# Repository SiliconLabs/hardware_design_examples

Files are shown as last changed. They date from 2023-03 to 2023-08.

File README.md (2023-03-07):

<table border="0">
  <tr>
    <td align="left" valign="middle">
    <h1>Hardware Design Examples</h1>
  </td>
  <td align="left" valign="middle">
    <a href="https://www.silabs.com/wireless">
      Wireless and RF Solutions
    </a>
  </td>
  </tr>
</table>

# Silicon Labs Hardware Design Examples #

This repository contains hardware design examples using Silicon Labs' devices. The main purpose of these examples is to accelerate the initial development process by providing a ready-to-use hardware platform.

Besides the design files, typically a test report and/or a user's manual is included summarizing some performance details of a built test unit sample.

## How to use the examples ##
The designs include complete manufacturing data files that can be used to fabricate the PCBs and pupolate them with the required components. After these steps the assembled units can be used to start the software/firmware development.

The designs can be also used as a starting point for further hardware development and modified freely according to the specific requirements.

## Organization of the Hardware Design Examples (Branches and Folders) ##
The examples are organized into branches of this repository based on the used device family. The designs belonging to the same device family can be found in the branch named accordingly.

Under the branches the folder naming convention is the following:

DeviceFamily_PackageType_Frequency_TXPower_NumberOfPCBLayers_OtherInformation\

## Examples ##

For a list of examples in this repository see the README content on the master branch.

## Disclaimer / Terms and Conditions ##

The Hardware Design Examples in this repository are provided AS IS. By downloading and using them, the user assumes and bears all liability emerging from the application of these examples.

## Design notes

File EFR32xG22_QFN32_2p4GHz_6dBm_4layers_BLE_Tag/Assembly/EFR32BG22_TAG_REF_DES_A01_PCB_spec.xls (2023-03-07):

PCB Specification of EFR32BG22_TAG_REF_DES_A01 Silicon Labs |  |  | 2020-07-06
Revision history
1
REVISION |  | 1
MECHANICAL SPECIFICATION
PCB Name |  | BG22_Tag
PCB size
Tolerances for all the dimensions |  | IPC600A(G) class 2
Core Material |  | FR-4, UL 94V-0
Substarte construction
Operating temperature range |  | -
Copper | 18um
 | prepreg 1080 63um
Copper | 18um
FR4 | Core FR4 510um 18/18
Copper | 18um
 | prepreg 1080 63um
Copper | 18um
Surface Finnishing
 | Conductor Plating | Copper
 | Pad/Land Pattern Coating | Immersion Gold
 | Solder Resist | Blue
Controlled impedance |  | NO
Silckscreen |  | YES/Top
Number of Layers |  | 4
Total Number of Drilled Holes
DESIGN RULES
Minimum Conductor Width |  | 100 um
Minimum Clearance |  | 150 um
Minimum PTH Drill Size |  | 200 um
Minimum Annular Ring |  | 100 um
TEST SPECIFICATION
Electrical Testing |  | Double side 100 % electrical testing
ADDITIONAL INFORMATION
Related CAM files |  | EFR32BG22_TAG_REF_DES_A01_Gerbers.zip
Specificatio Approved:
Customer:
Name:
Date:

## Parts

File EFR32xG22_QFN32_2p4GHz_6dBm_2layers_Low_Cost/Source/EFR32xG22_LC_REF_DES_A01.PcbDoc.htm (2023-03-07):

Date | : | 2022. 03. 07.
Time | : | 15:21:19
Filename | : | C:\Users\dasimon\Dropbox (Silicon Labs)\IoT Apps Wireless HW\Virtual Reference Designs\EFR32xG22_LC_REF_DES\release\latest\EFR32xG22_LC_REF_DES_A02\Source\EFR32xG22_LC_REF_DES_A01.PcbDoc
Version | Warning
Release 17.0 | CAUTION - Component parameters added.
Release 17.0 | CAUTION - Support of backdrilling
Release 17.1 | CAUTION - Support of waived violations
Release 17.1 | CAUTION - Support of object specific keepouts

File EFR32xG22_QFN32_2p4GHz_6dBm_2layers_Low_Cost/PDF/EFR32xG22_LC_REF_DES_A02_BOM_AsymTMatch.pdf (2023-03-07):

EFR32xG22 Low Cost Reference Design EFR32xG22_LC_REF_DES, Revision A02

Bill of Materials

ITEM | QTY | REFDES | DESCRIPTION | MANUFACTURER | PART NUMBER
1 | 1 | C2 | CAPACITOR, CERAMIC, 1.3PF, ±0.1PF, 50V, 0201 (0603 METRIC) | MURATA | GRM0335C1H1R3BA01D
2 | 1 | Z1 | INDUCTOR, THICK FILM, 3.0NH, ±0.1NH, 500MA 200mOhm Max 0201 (0603 METRIC) | MURATA | LQP03TN3N0B02D
3 | 1 | Z2 | CAPACITOR, CERAMIC, 18PF, ±1%, 25V, 0201 (0603 METRIC) | MURATA | GJM0335C1E180GB01D
4 | 5 | C4, C6, C9, C13, C15 | CAPACITOR, CERAMIC, 0.1UF, ±10%, 25V, 0201 (0603 METRIC) | MURATA | GRM033C81E104KE14D (https://www.digikey.com/product-detail/en/murata-electronics/GRM033C81E104KE14D/490-10403-1-ND/5026280)
5 | 2 | C5, C7 | CAPACITOR, CERAMIC,120PF, 50V, ±5% 0201 (0603 METRIC) | MURATA | GRM0335C1H121FA01D
6 | 1 | C8 | CAPACITOR, CERAMIC, 10UF, ±10%, 25V, 0603 (1608 METRIC) | MURATA | GRM188R61E106KA73D (https://www.digikey.com/product-detail/en/murata-electronics/GRM188R61E106KA73D/490-18214-1-ND/9867943)
7 | 1 | C10 | CAPACITOR, CERAMIC, 1UF, ±10%, 25V, 0402 (1005 METRIC) | MURATA | GRM155R61E105KA12D
8 | 1 | C11 | CAPACITOR, CERAMIC, 10NF, ±10%, 25V, 0201 (0603 METRIC) | MURATA | GRM033R71E103KE14D
9 | 1 | C12 | CAPACITOR, CERAMIC, 1UF, ±10%, 25V, 0603 (1608 METRIC) | MURATA | GCM188R71E105KA64D
10 | 1 | C14 | CAPACITOR, CERAMIC, 4.7UF, ±10%, 6.3V, 0603 (1608 METRIC) | SAMSUNG ELECTRO-MECHANICS | CL10B475KQ8NQNC
11 | 1 | C16 | CAPACITOR, CERAMIC, 1UF, ±10%, 25V, 0201 (0603 METRIC) | SAMSUNG ELECTRO-MECHANICS | CL03A105KP3NSNC
12 | 1 | C18 | CAPACITOR, CERAMIC, 1UF, ±10%, 25V, 0805 (2012 METRIC) | SAMSUNG ELECTRO-MECHANICS | CL21B105KAFNNNE
13 | 1 | L1 | INDUCTOR, THICK FILM, 2.7NH, ±0.1NH, 500MA 200mOhm Max 0201 (0603 METRIC) | MURATA | LQP03TN2N7B02D
14 | 2 | L2, L3 | FERRITE BEAD, 1 KOMHS @ 100MHZ, 350MA, 0402 (1005 METRIC) | MURATA | BLM15AX102SZ1D (https://www.digikey.com/product-detail/en/murata-electronics/BLM15AX102SZ1D/490-16654-1-ND/7595576)
15 | 1 | L5 | INDUCTOR, MULTILAYER, 2.2UH, 750MA 300mOHMS 0603 (1608 METRIC) | TDK | CIG10W2R2MNC (https://www.digikey.com/product-detail/en/samsung-electro-mechanics/CIG10W2R2MNC/1276-6877-1-ND/7041277)
16 | 1 | P1 | CONN HEADER SMD 10POS 1.27MM | SAMTEC INC. | FTSH-105-01-F-DV-K
17 | 1 | P2 | CONNECTOR, U.FL ,RF COAXIAL, SMT | TE CONNECTIVITY | 1909763-1
18 | 1 | PCB1 | PRINTED CIRCUIT BOARD
19 | 6 | R1, R2, R4, R8, R10,R13 | RESISTOR, THICK FILM, 0 OHM, JUMPER, 0.05W, 1/20W, 0201 (0603 METRIC) | PANASONIC | ERJ-1GN0R00C (https://www.digikey.com/product-detail/en/panasonic-electronic-components/ERJ-1GN0R00C/P15979CT-ND/3982319)
20 | 1 | U1 | IC, COMMUNICATIONS, EFR32MG22, -40C TO 125C, SOC, ARM CORTEX-M33, 32K RAM, 512K FLASH, 32-QFN | SILICON LABS | EFR32MG22A224F512GN32 - C
21 | 1 | X1 | OSCILLATOR, CRYSTAL, 38.4MHZ, ±10PPM, 10PF | TAI-SAW | TZ2205E
22 | 1 | X2 | OSCILLATOR, CRYSTAL, 32.768KHZ, ±20PPM, 7PF, 2-SMD | EPSON | FC-135 32.7680KA-AG5
23 | 1 | BAT1 | BATTERY HOLDER COIN 20MM SMD | MPD (MEMORY PROTECTION DEVICES) | BU2032SM-JJ-GTR
24 | 1 | L4 | INDUCTOR, THICK FILM, 5.1NH, ±3%, 350MA 400mOhm Max 0201 (0603 METRIC) | MURATA | LQP03TN5N1H02
25 | 1 | C19 | CAPACITOR, CERAMIC, 0.7PF, ±0.05PF, 50V, 0201 (0603 METRIC) | MURATA | GRM0335C1HR70WA01
Total | 36

EFR32xG22 Low Cost Reference Design EFR32xG22_LC_REF_DES, Revision A02

Reduced Bill of Materials

ITEM | QTY | REFDES | DESCRIPTION | MANUFACTURER | PART NUMBER
1 | 1 | C2 | CAPACITOR, CERAMIC, 1.3PF, ±0.1PF, 50V, 0201 (0603 METRIC) | MURATA | GRM0335C1H1R3BA01D
2 | 1 | Z1 | INDUCTOR, THICK FILM, 3.0NH, ±0.1NH, 500MA 200mOhm Max 0201 (0603 METRIC) | MURATA | LQP03TN3N0B02D
3 | 1 | Z2 | CAPACITOR, CERAMIC, 18PF, ±1%, 25V, 0201 (0603 METRIC) | | GJM0335C1E180GB01D
4 | 1 | C4 | CAPACITOR, CERAMIC, 0.1UF, ±10%, 25V, 0201 (0603 METRIC) | MURATA | GRM033C81E104KE14D (https://www.digikey.com/product-detail/en/murata-electronics/GRM033C81E104KE14D/490-10403-1-ND/5026280)
5 | 2 | C5,C7* | CAPACITOR, CERAMIC,120PF, 50V, ±5% 0201 (0603 METRIC) | MURATA | GRM0335C1H121FA01D
6 | 1 | C8 | CAPACITOR, CERAMIC, 10UF, ±10%, 25V, 0603 (1608 METRIC) | MURATA | GRM188R61E106KA73D (https://www.digikey.com/product-detail/en/murata-electronics/GRM188R61E106KA73D/490-18214-1-ND/9867943)
7 | 1 | C10 | CAPACITOR, CERAMIC, 1UF, ±10%, 25V, 0402 (1005 METRIC) | MURATA | GRM155R61E105KA12D
8 | 1 | C14 | CAPACITOR, CERAMIC, 4.7UF, ±10%, 6.3V, 0603 (1608 METRIC) | SAMSUNG ELECTRO-MECHANICS | CL10B475KQ8NQNC
9 | 1 | C16 | CAPACITOR, CERAMIC, 1UF, ±10%, 25V, 0201 (0603 METRIC) | SAMSUNG ELECTRO-MECHANICS | CL03A105KP3NSNC
10 | 1 | C18 | CAPACITOR, CERAMIC, 1UF, ±10%, 25V, 0805 (2012 METRIC) | SAMSUNG ELECTRO-MECHANICS | CL21B105KAFNNNE
11 | 1 | L1 | INDUCTOR, THICK FILM, 2.7NH, ±0.1NH, 500MA 200mOhm Max 0201 (0603 METRIC) | MURATA | LQP03TN2N7B02D
12 | 1 | L2 | FERRITE BEAD, 1 KOMHS @ 100MHZ, 350MA, 0402 (1005 METRIC) | MURATA | BLM15AX102SZ1D (https://www.digikey.com/product-detail/en/murata-electronics/BLM15AX102SZ1D/490-16654-1-ND/7595576)
13 | 1 | L5 | INDUCTOR, MULTILAYER, 2.2UH, 750MA 300mOHMS 0603 (1608 METRIC) | TDK | CIG10W2R2MNC (https://www.digikey.com/product-detail/en/samsung-electro-mechanics/CIG10W2R2MNC/1276-6877-1-ND/7041277)
14 | 1 | P1 | CONN HEADER SMD 10POS 1.27MM | SAMTEC INC. | FTSH-105-01-F-DV-K
15 | 1 | P2 | CONNECTOR, U.FL ,RF COAXIAL, SMT | TE CONNECTIVITY | 1909763-1
16 | 1 | PCB1 | PRINTED CIRCUIT BOARD
17 | 6 | R1, R2, R4, R8, R10,R13 | RESISTOR, THICK FILM, 0 OHM, JUMPER, 0.05W, 1/20W, 0201 (0603 METRIC) | PANASONIC | ERJ-1GN0R00C (https://www.digikey.com/product-detail/en/panasonic-electronic-components/ERJ-1GN0R00C/P15979CT-ND/3982319)
18 | 1 | U1 | IC, COMMUNICATIONS, EFR32MG22, -40C TO 125C, SOC, ARM CORTEX-M33, 32K RAM, 512K FLASH, 32-QFN | SILICON LABS | EFR32MG22A224F512GN32 - C
19 | 1 | X1 | OSCILLATOR, CRYSTAL, 38.4MHZ, ±10PPM, 10PF | TAI-SAW | TZ2205E
20 | 1 | X2 | OSCILLATOR, CRYSTAL, 32.768KHZ, ±20PPM, 7PF, 2-SMD | EPSON | FC-135 32.7680KA-AG5
21 | 1 | BAT1 | BATTERY HOLDER COIN 20MM SMD | MPD (MEMORY PROTECTION DEVICES) | BU2032SM-JJ-GTR
22 | 1 | L3 | RESISTOR, THICK FILM, 0 OHM, JUMPER, 0402 (1005 METRIC)
23 | 1 | L4 | INDUCTOR, THICK FILM, 5.1NH, ±3%, 350MA 400mOhm Max 0201 (0603 METRIC) | MURATA | LQP03TN5N1H02
24 | 1 | C19 | CAPACITOR, CERAMIC, 0.7PF, ±0.05PF, 50V, 0201 (0603 METRIC) | MURATA | GRM0335C1HR70WA01
Total | 30

Notes:
*C7 is not needed for devices with maximum output power of 0 dBm

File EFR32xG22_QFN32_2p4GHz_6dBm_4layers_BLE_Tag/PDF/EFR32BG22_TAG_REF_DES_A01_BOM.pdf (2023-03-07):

Bill Of Materials for EFR32BG22_TAG_REF_DES_A00.sch on Thu Jul 23 10:30:01 2020
Column1 | Column2 | Column3 | Column4 | Column5 | Column6 | Column7 | Column8 | Column9 | Column10
Item | Quantity | Reference | Value | Manufacturer | Part Number | Description | Tolerance | Package | Distributor
1 | 1 | U3 | | Bosch Sensortec | BMA400 | Accelerometer 2-16G 12LGA | | 12-LGA (2x2mm) | Digikey
2 | 5 | C6, C11, C13, C16, C21 0.1uF | any | General Ceramic Chip Capacitor | +/-10% | 0201
3 | 2 | C7, C12 | 12pF | any | | Ceramic Chip Capacitor | +/-2% | 0201
4 | 1 | C17 | 18pF | Murata | GJM0335C1E180GB01D | Ceramic Chip Capacitor | +/-2% | 0201
5 | 1 | C3 | 1.2pF | Murata | GRM0335C1H1R2WA01D | Ceramic Chip Capacitor | +/-0.05pF | 0201
6 | 1 | C2 | 1.3pF | Murata | GRM0335C1H1R3BA01D | Ceramic Chip Capacitor | +/-0.1pF | 0201
7 | 1 | C19 | NP | | | Ceramic Chip Capacitor | +/-0.1pF | 0201
8 | 5 | C9-10, C14-15 | 1uF | any | | Ceramic Chip Capacitor | +/-20% | 0201
| | C18
9 | 1 | C1 | 1.7pF | Murata | GRM0335C1H1R7BA01D | Ceramic Chip Capacitor | +/-0.1pF | 0201
10 | 1 | C4 | 2.2uF | any | | Ceramic Chip Capacitor | 10% | 0402
11 | 2 | C5 C8 | 4.7uF | any | | Ceramic Chip Capacitor | +/-20% | 0402
12 | 1 | Y3 | | MPD (Memory Protection
| | | | Devices) | BC-2003-TR | Battery Retainer Coin, 20.0mm 1 Cell
| | | | | | SMD (SMT) Tab, Coin cell CR2032
| | | | | | battery holder | | | Digikey
13 | 1 | U5 | | Infineon Technologies | DPS310XTSA1 | Pressure Sensor | | 8-pin LGA
14 | 1 | U1 | | Silicon Labs | EFR32BG22C224F512GM32 | | | QFN32
15 | 7 | TP1-7
16 | 1 | J1 | HEADER, 10PIN | Samtec | FTSH-105-01-F-DV | Header, 10 pin, SMD, 1.27mm, dual
| | | | | | row | | HEADER_10PIN_1.2
| | | | | | | | 7MM_SMD_DUAL | Q-Flex
17 | 7 | HOL1-7 | N/A | N/A | | N/A | | | N/A
18 | 2 | L1, L5 | 5.6nH | Murata | LQP03TN5N6H02D | Chip Coil | +-3% | 0201
19 | 1 | L2 | 6.2nH | Murata | LQP03TN6N2H02D | Chip Coil | +-3% | 0201
20 | 1 | L6 | 2.2µH | Taiyo Yuden | MAMK2520T2R2M | Shielded SMT Power Inductor | +/-20% | 1008
21 | 1 | L4 | 2.7nH | Murata | LQP03TN2N7B02D | Chip Inductor | +-0.1nH | 0201 | Digikey
22 | 1 | D1 | | Broadcom Limited | HSMC-C190 | Low-current LED | | 0603
23 | 1 | R5 | 0R | any | 232270671001L | Chip Resistor | N/A | 0201 | Arrow
24 | 1 | R9 | 2k | any | | Chip Resistor | N/A | 0201
25 | 1 | R2 | 0R | any | | Chip Resistor | N/A | 0402
26 | 1 | SW1 | | C&K Components | PTS820J_ | Tactile Switch, Microminiature SMT
| | | | | | Top Actuated
27 | 1 | Y1 | 32.768 kHz | AVX Corp/Kyocera Corp | ST2012SB32768C0HPWBB Crystal, 32.768 kHz, CL=7pF | 20ppm | 2.0x1.2mm
28 | 1 | Y2 | 38.4MHz | Siward Crystal Technology | XTL501200-C294-002 | Crystal, 38.4000 Mhz, 9pF -40..+85C,
| | | | | | CL=10pF, C0=3pF | 10ppm/20ppm | 2.0x1.6mm 4-pad

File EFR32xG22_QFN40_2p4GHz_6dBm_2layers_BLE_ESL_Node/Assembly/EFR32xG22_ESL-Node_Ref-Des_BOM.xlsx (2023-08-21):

Quantity | Designator | Value | Manufacturer | Part Number | Description | Comment | Tolerance | Rating | Package | Technology | Not mounted
2 | BATT1, BATT2 |  | Keystone Electronics Corp. | 2450 SMT battery holder 1052 | https://hu.mouser.com/datasheet/2/215/052-743285.pdf | BATTERY_HOLDER
5 | C1, C6, C8, C19, C28 | 100nF | Murata |  | Capacitor - ceramic |  | 10% | 10V | SMD0201 | X5R
1 | C2 | 10uF | Murata |  | Capacitor - ceramic |  | 20% | 6.3V | SMD0402 | X5R
1 | C3 | 10nF | Murata |  | Capacitor - ceramic |  | 10% | 10V | SMD0201 | X5R
1 | C4 | 1uF | Murata |  | Capacitor - ceramic |  | 20% | 6.3V | SMD0402 | X5R
2 | C5, C9 | 1uF | Murata |  | Capacitor - ceramic |  | 20% | 10V | SMD0201 | X5R
1 | C7 | 4.7uF | Murata |  | Capacitor - ceramic |  | 20% | 10V | SMD0402 | X5R
2 | C10, C12 | 15pF | Murata | GRM0335C series | Capacitor - ceramic |  | 5% |  | SMD0201 | C0G
4 | C11, C13, C20, C29 | 220nF | Murata |  | Capacitor - ceramic |  | 10% | 10V | SMD0201 | X5R
4 | C14, C15, C16, C17 |  |  |  | Capacitor - ceramic | N.M. |  |  |  |  | N.M.
2 | C18, C37[1] | 1uF | Murata |  | Capacitor - ceramic |  | 10% | 10V | SMD0402 | X5R
4 | C21[1], C22[1], C24[1], C25[1] |  |  |  | Capacitor - ceramic | N.M. |  |  | SMD0805 |  | N.M.
1 | C21[2] | 100uF | Murata |  | Capacitor - ceramic | N.M. | 20% | 6V3 | SMD1206 | X5R | N.M.
2 | C22[2], C25[2] |  |  |  | Capacitor - ceramic | N.M. |  |  | SMD1206 |  | N.M.
3 | C23, C26, C27 | 100nF | Murata |  | Capacitor - ceramic |  | 10% | 16V | SMD0402 | X7R
1 | C24[2] | 100uF | Murata |  | Capacitor - ceramic |  | 20% | 6V3 | SMD1206 | X5R
1 | C30 | 7.5pF | Murata |  | Capacitor - ceramic |  | 0.25pF | 50V | SMD0201 | NP0
1 | C31 |  |  |  | Capacitor - ceramic | N.M. |  |  | SMD0201 |  | N.M.
2 | C32, C33 | 10uF | Murata |  | Capacitor - ceramic |  | 10% | 25V | SMD0603 | X5R
1 | C34 | 0.33uF | Murata |  | Capacitor - ceramic |  | 10% | 25V | SMD0603 | X5R
8 | C35[1], C36[1], C38[1], C39[1], C40[1], C41[1], C42[1], C43[1] |  |  |  | Capacitor - ceramic | N.M. |  |  | SMD0402 |  | N.M.
6 | C35[2], C38[2], C39[2], C40[2], C41[2], C43[2] | 1uF | Murata |  | Capacitor - ceramic |  | 10% | 25V | SMD0603 | X5R
1 | C36[2] | 10uF | Murata |  | Capacitor - ceramic |  | 10% | 10V | SMD0603 | X5R
1 | C37[2] |  |  |  | Capacitor - ceramic | N.M. | 10% | 25V | SMD0603 | X5R | N.M.
1 | C42[2] | 4.7uF | Murata |  | Capacitor - ceramic |  | 10% | 25V | SMD0603 | X5R
1 | CC1 | 15pF | Murata | GRM0335C series | Capacitor - ceramic |  | 5% |  | SMD0201 | C0G
3 | CM1, CM3, CM4 |  | Murata | GRM0335C series | Capacitor - ceramic | N.M. |  |  | SMD0201 | C0G | N.M.
1 | CM2 | 1.2pF | Murata | GRM0335C series | Capacitor - ceramic |  | 0.1pF |  | SMD0201 | C0G
1 | D1 |  | Broadcom | ASCB-JTC2-0A308 | https://docs.broadcom.com/doc/ASCB-JTC2-0A308-1615-Tricolor-PLCC-4-LED-DS | 1615 Tricolor PLCC-4 LED |  |  | 1.6×1.5×1.0 mm PLCC-4 package
1 | D2 |  | ON Semiconductor | SZESD7451 | Bidirectional ESD Protection Diode |  |  |  | SOD882
3 | D3[1], D4[1], D5[1] |  | NEX (Nexperia) | PMEG4010BEA | 1A very low Vf MEGA Schottky barrier rectifier. | N.M. |  |  | SOD-323 |  | N.M.
3 | D3[2], D4[2], D5[2] |  | NEX (Nexperia) | PMEG3005EL | 30 V, 0.5A low VF MEGA Schottky barrier rectifier |  |  |  | SOD-882
1 | J1 |  | Samtec | FTSH-105-01-L-DV-K | 10-pin mini-simplicity header | FTSH_105_01_L_DV_K
7 | J2, J3, J4, J5, J6, J7, J9 |  | Amphenol ICC (FCI) | 75160-101-02LF | CONN HEADER VERT 2POS 2.54MM | Jumper_2.54mm
2 | J8, J10 |  | Amphenol ICC (FCI) | 75160-101-03LF | CONN HEADER VERT 3POS 2.54MM | Jumper_2.54mm_3p
1 | J11 |  | Amphenol ICC (FCI) | 75160-101-05LF | CONN HEADER VERT 5POS 2.54MM | Jumper_2.54mm_5p
1 | J12 |  | Hirose Electric Co. Ltd. | FH34SRJ-24S-0.5SH | FPC Connector for EPD, 0.5mm pitch, 24 pins, dual contact |  |  | 50V
1 | J13 |  | Hirose Electric Co. Ltd. | FH34SRJ-6S-0.5SH-1 | FPC Connector for Touch Interface, 0.5mm pitch, 6 pins |  |  | 50V
1 | L1[1] | 2.2uH | Murata | LQM18FN2R2M00 | DCDC Output Inductor | loss: 520mR | 20% | 120mA | SMD0603 |  | N.M.
1 | L1[2] | 2.2uH | Murata | LQM21PN2R2NGCD | DCDC Output Inductor | loss: 288mR | 30% | 800mA | SMD0805
2 | L2[1], L3[1] | 22nH |  |  | Inductor | N.M. |  |  | SMD0402 |  | N.M.
2 | L2[2], L3[2] | 1000R | Murata | BLM18AG102SN1 | Ferrite Inductor | DCR=0R5 | 25% | 400mA | SMD0603
1 | L4[1] | 47uH |  |  | Inductor | N.M. |  |  | SMD0805 |  | N.M.
1 | L4[2] | 10uH | Taiyo Yuden | BRC2016T100M | Inductor | 520mR | 20% | 450mA | SMD0806
1 | L4[3] |  |  |  | Inductor | N.M. |  |  | 2.5x2.0x1.2 (2520) |  | N.M.
1 | L4[4] | 10uH | TAY |  | Inductor | 450mR | 20% | 0.5A |  |  | N.M.
2 | LM1, LM2 | 2.7nH | Murata | LQP03TN2N7B02 (LQP03TN series) | Inductor |  | 0.1nH |  | SMD0201
1 | LM3 |  | Murata | LQP03TN series | Inductor | N.M. | 3% |  | SMD0201 |  | N.M.
3 | R1, R31, R40 | 0R |  |  | Resistor | N.M. |  |  | SMD0201 |  | N.M.
5 | R2, R5, R32, R39, RM1 | 0R |  |  | Resistor |  |  |  | SMD0201
7 | R3, R16, R17, R19, R33, R35, R36 | 0R |  |  | Resistor |  |  |  | SMD0603
6 | R4, R22, R23, R30, R37, R38 | 0R |  |  | Resistor | N.M. |  |  | SMD0603 |  | N.M.
1 | R6 | 470R |  |  | Resistor |  |  |  | SMD0201
3 | R7, R9, R12 | 0R |  |  | Resistor |  |  |  | SMD0402
3 | R8, R10, R11 | 0R |  |  | Resistor | N.M. |  |  | SMD0402 |  | N.M.
3 | R13, R14, R15 | 4k7 | Yageo |  | Resistor |  | 5% |  | SMD0201
1 | R18 | 330k |  |  | Resistor |  |  |  | SMD0201
4 | R20, R27, R28, R29 | 100k | Yageo |  | Resistor |  | 5% |  | SMD0201
1 | R21 | 10k | Yageo |  | Resistor |  | 5% |  | SMD0201
2 | R24, R25 | 100R | Yageo |  | Resistor |  | 5% |  | SMD0201
1 | R26 | 270R | Yageo |  | Resistor |  | 5% |  | SMD0201
1 | R34 |  |  |  | Resistor | N.M. |  |  | SMD0201 |  | N.M.
1 | R41 | 0R47 |  |  | Resistor |  | 1% |  | SMD0402
2 | SW1, SW2 |  | CK Components | PTS810 SJM 250 SMTR LFS | User and Reset push button | PTS810
1 | T1 |  | NEX (Nexperia) | PMZ350UPE | P-Channel Trench MOSFET |  |  | 30V | SOT-883
1 | T2 |  | NEX (Nexperia) | PMCB60XNZ | N-Channel Trench MOSFET |  |  | 30V | SOT8026
3 | T3, T4, T5 |  | NEX (Nexperia) | PMZ200UNE; PMZ370UNEYL | N-Channel Trench MOSFET |  |  | 30V | SOT-883
1 | U1 |  | Silicon Labs | EFR32BG22C224F512GM40 | 40-pin Wireless (BLE) MCU | EFR32BG22C224F512GM40 |  |  | QFN40
1 | U2[1] |  | Macronix | MX25R8035FM1IL0 | ULTRA LOW POWER, 8M-BIT FLASH MEMORY | MX25R8035F |  |  | 8-SOP (150mil)
1 | U2[2] |  | Macronix | MX25R8035FM2IL0; MX25R8035FM2IH0 | ULTRA LOW POWER, 8M-BIT FLASH MEMORY | MX25R8035F |  |  | 8-SOP (200mil) |  | N.M.
1 | U3[1] |  | NXP | NT3H2111W0FT1 | NFC NTAG | NT3H2111W0FT1/NXP/SO8 |  |  | SO8 |  | N.M.
1 | U3[2] |  | NXP | NT3H2111W0FHK | NFC NTAG | NT3H2111/NXP/XQFN-8 |  |  | XQFN-8
1 | U4 |  | Bosch Sensortec | BMA400 | Accelerometer 2-16G 12-LGA | BMA400 |  |  | 12-LGA (2x2mm)
1 | U5 |  | Maxim Integrated | MAX1759 | https://datasheets.maximintegrated.com/en/ds/MAX1759.pdf | Buck/Boost Regulating Charge Pump in µMAX |  | 5.5 V | 10-pin µMAX
1 | Y1 | 38.4MHz | KDS; Abracon LLC | DSX211SH 1ZZNAE38400AB0A; ABM11W-38.4000MHZ-8-B1U-T3 | HFXO | accuracy: 10ppm; load capacitance: 8pF | 10ppm |  | 2.0x1.6x0.5mm
1 | Y2 | 32.768kHz | KDS; Micro Crystal AG | DST210A 1TJG125DP1A0012; CM8V-T1A-32.768KHZ-9PF-20PPM-TA-QC | LFXO | accuracy: 12.5ppm | 20ppm |  | 2.0x1.2x0.55mm

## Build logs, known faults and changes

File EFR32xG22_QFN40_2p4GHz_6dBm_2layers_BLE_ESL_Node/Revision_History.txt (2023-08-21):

Rev A02:
Fixing DCDC configuration mounting options
Fixing BMA400 interface mounting options
Fixing silk screen and DRC errors

Rev A01:
Adding VEXT connector to support external supply
Adding Touch Interface
Adding test header for I2C
Fixing RGB LED pin mapping
32kHz crystal pad area fix
EPD DCDC switching FET changed to PMCB60XNZ

Rev A00: 
Original release

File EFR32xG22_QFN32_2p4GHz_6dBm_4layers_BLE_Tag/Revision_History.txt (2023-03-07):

Rev A00: 
Original release

Rev A01:
- R9 resistor value change to 2kOhm
- Fixing LED orientation by rotating it by 180 degrees

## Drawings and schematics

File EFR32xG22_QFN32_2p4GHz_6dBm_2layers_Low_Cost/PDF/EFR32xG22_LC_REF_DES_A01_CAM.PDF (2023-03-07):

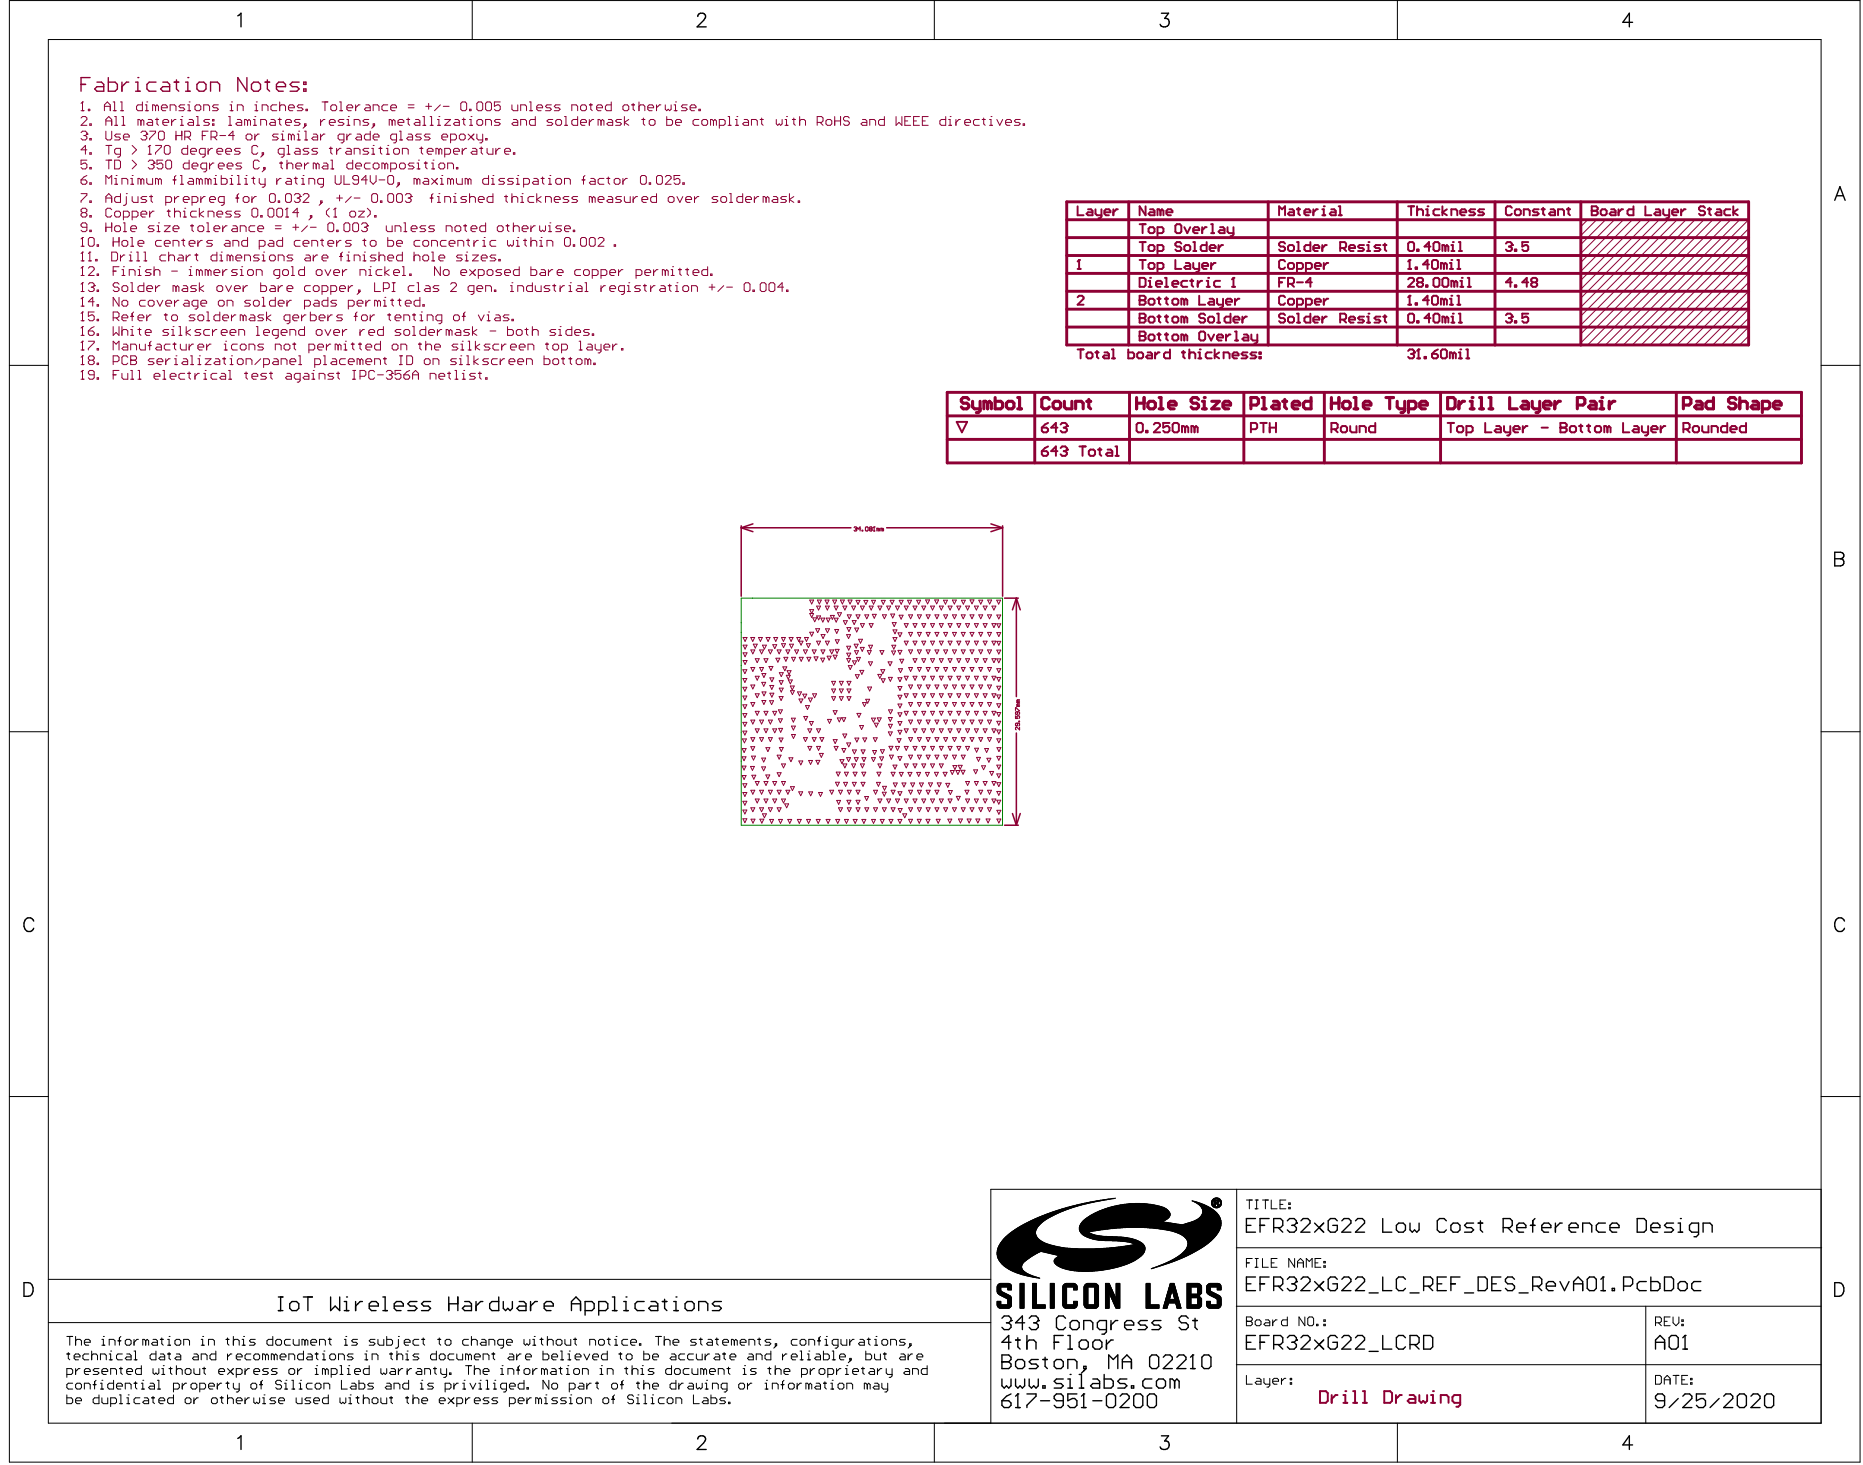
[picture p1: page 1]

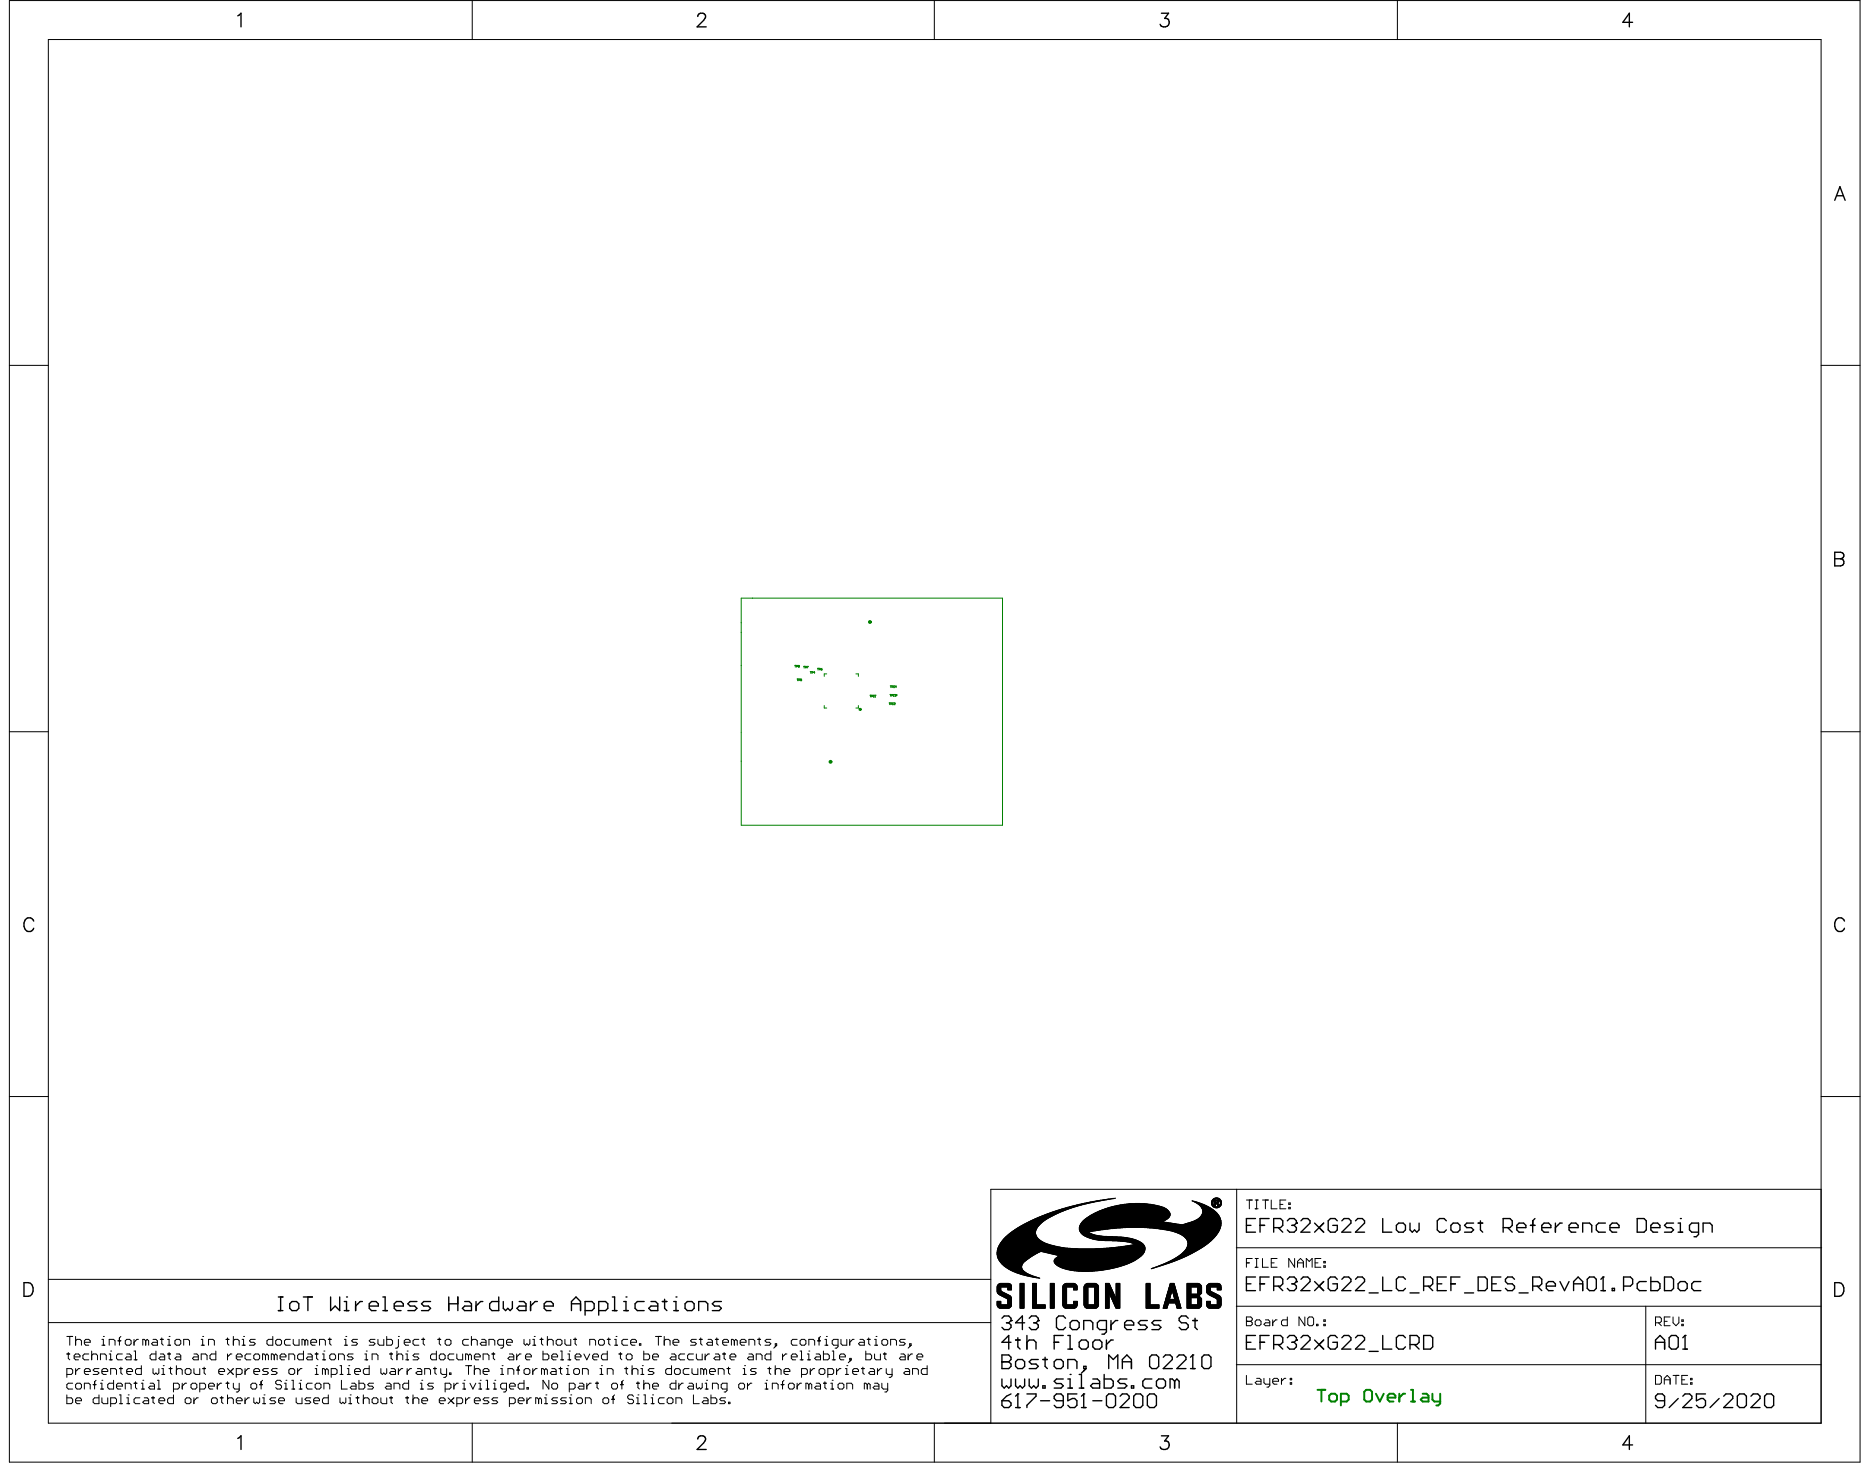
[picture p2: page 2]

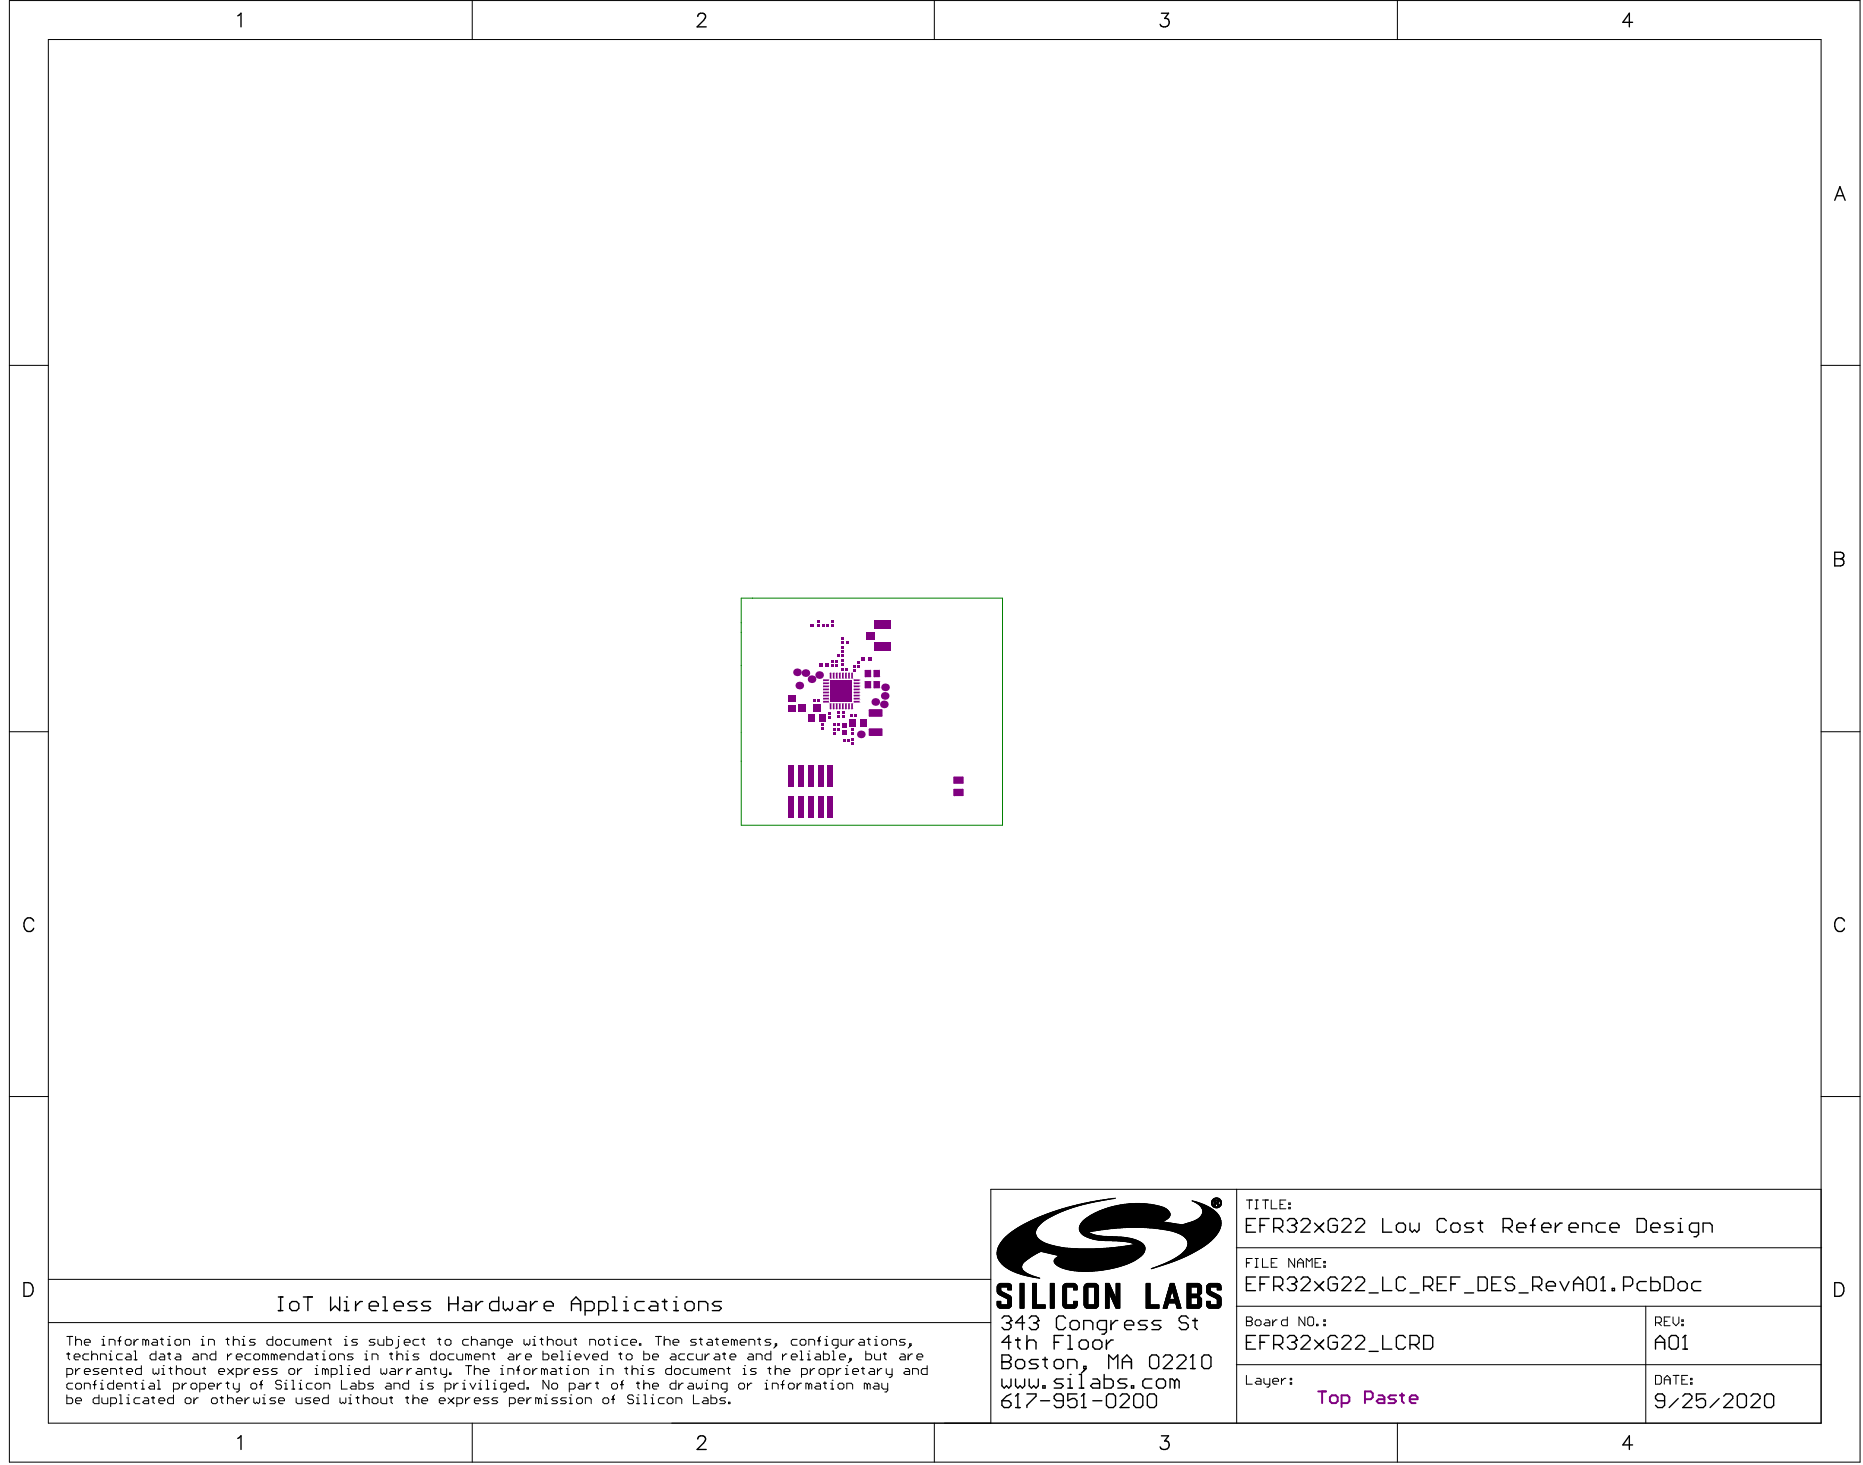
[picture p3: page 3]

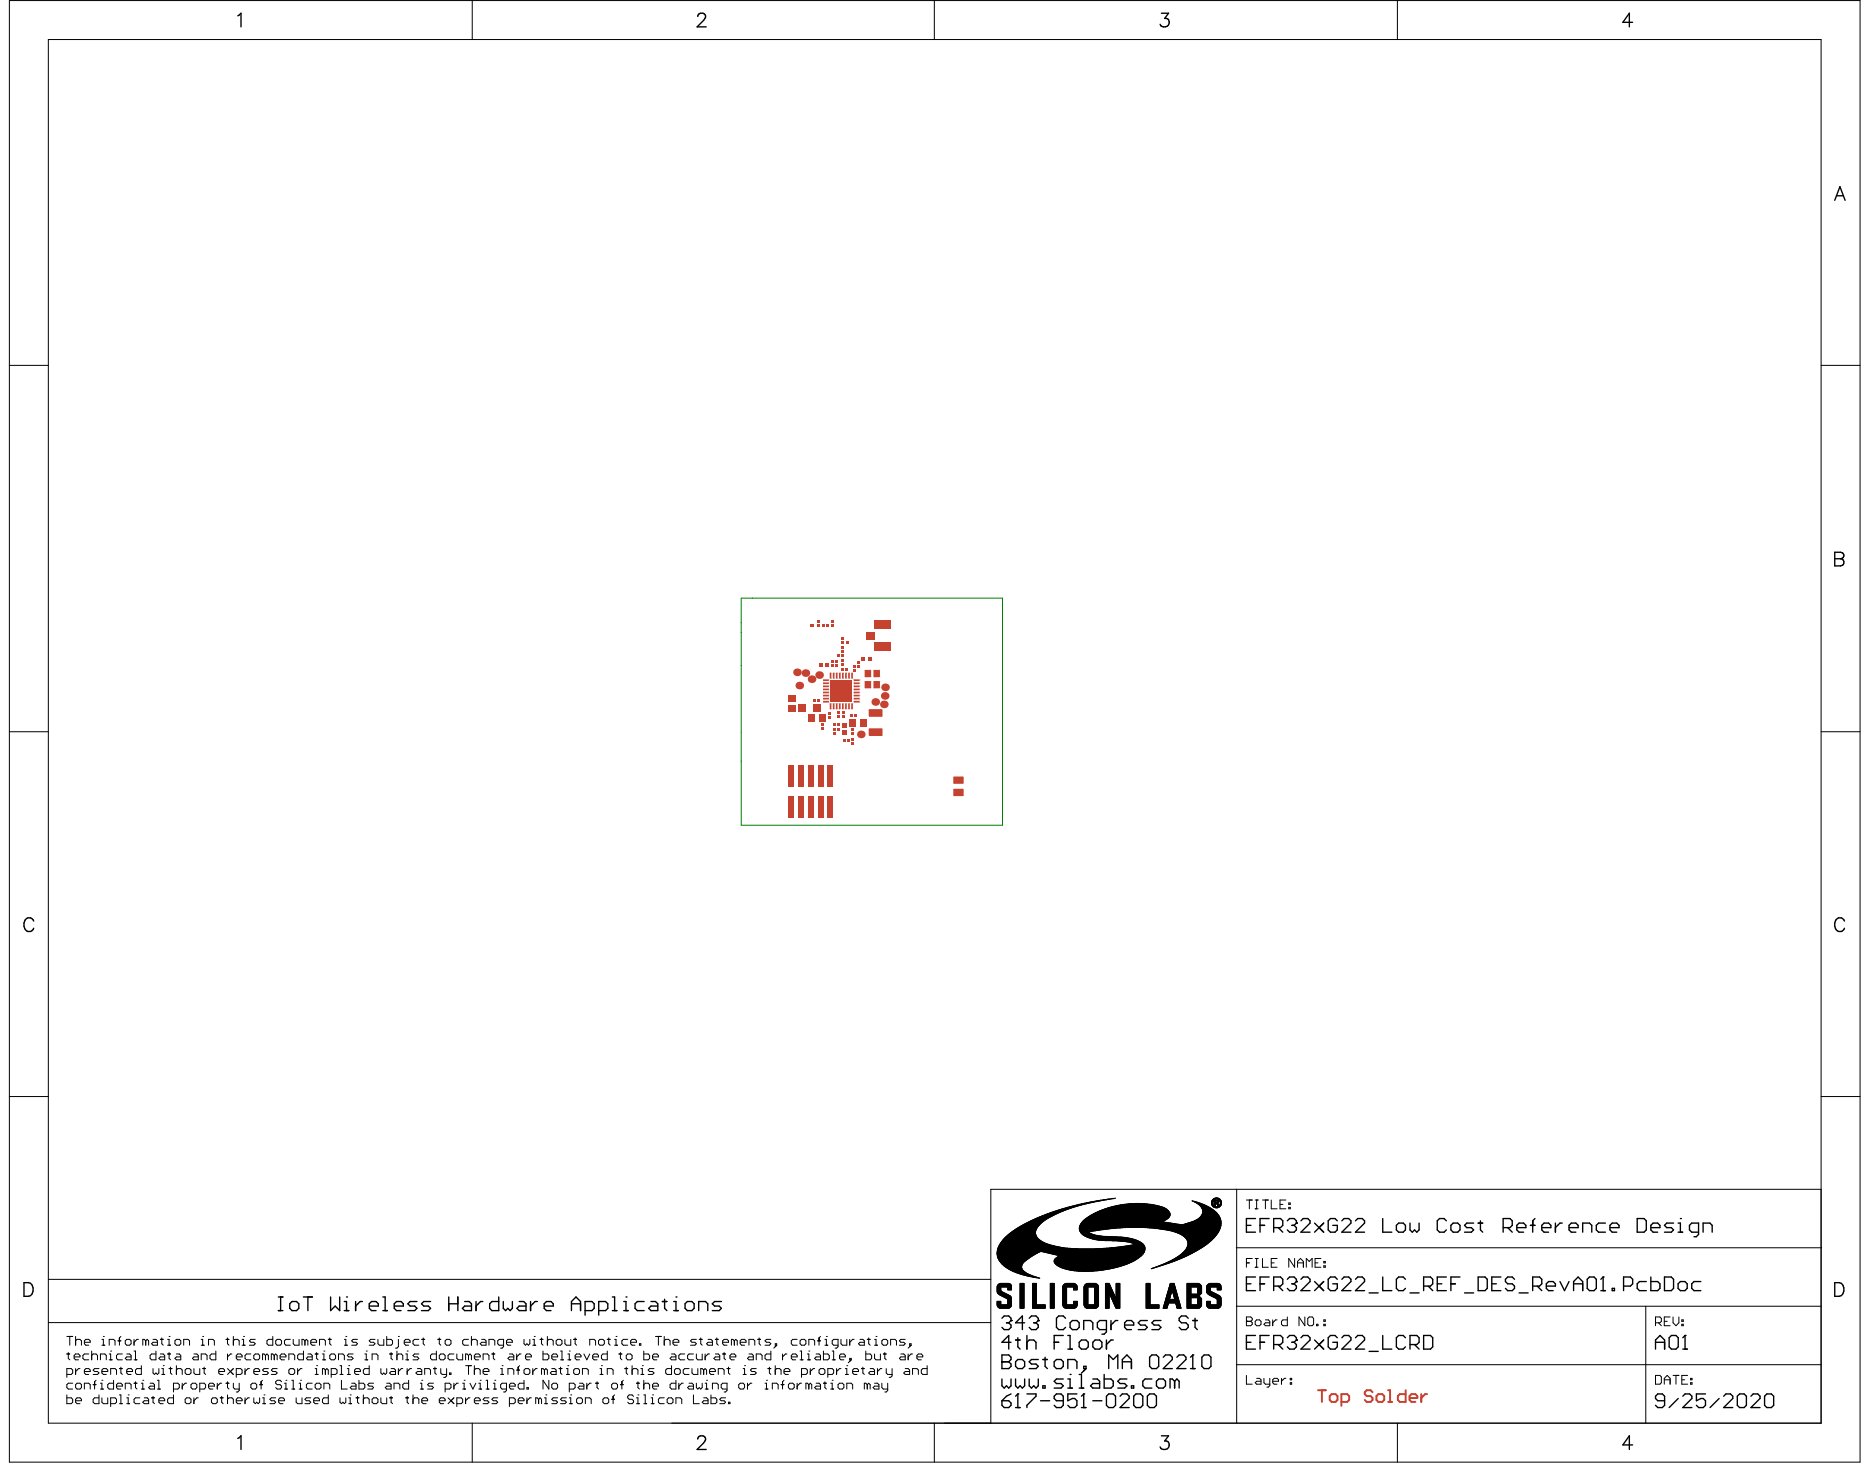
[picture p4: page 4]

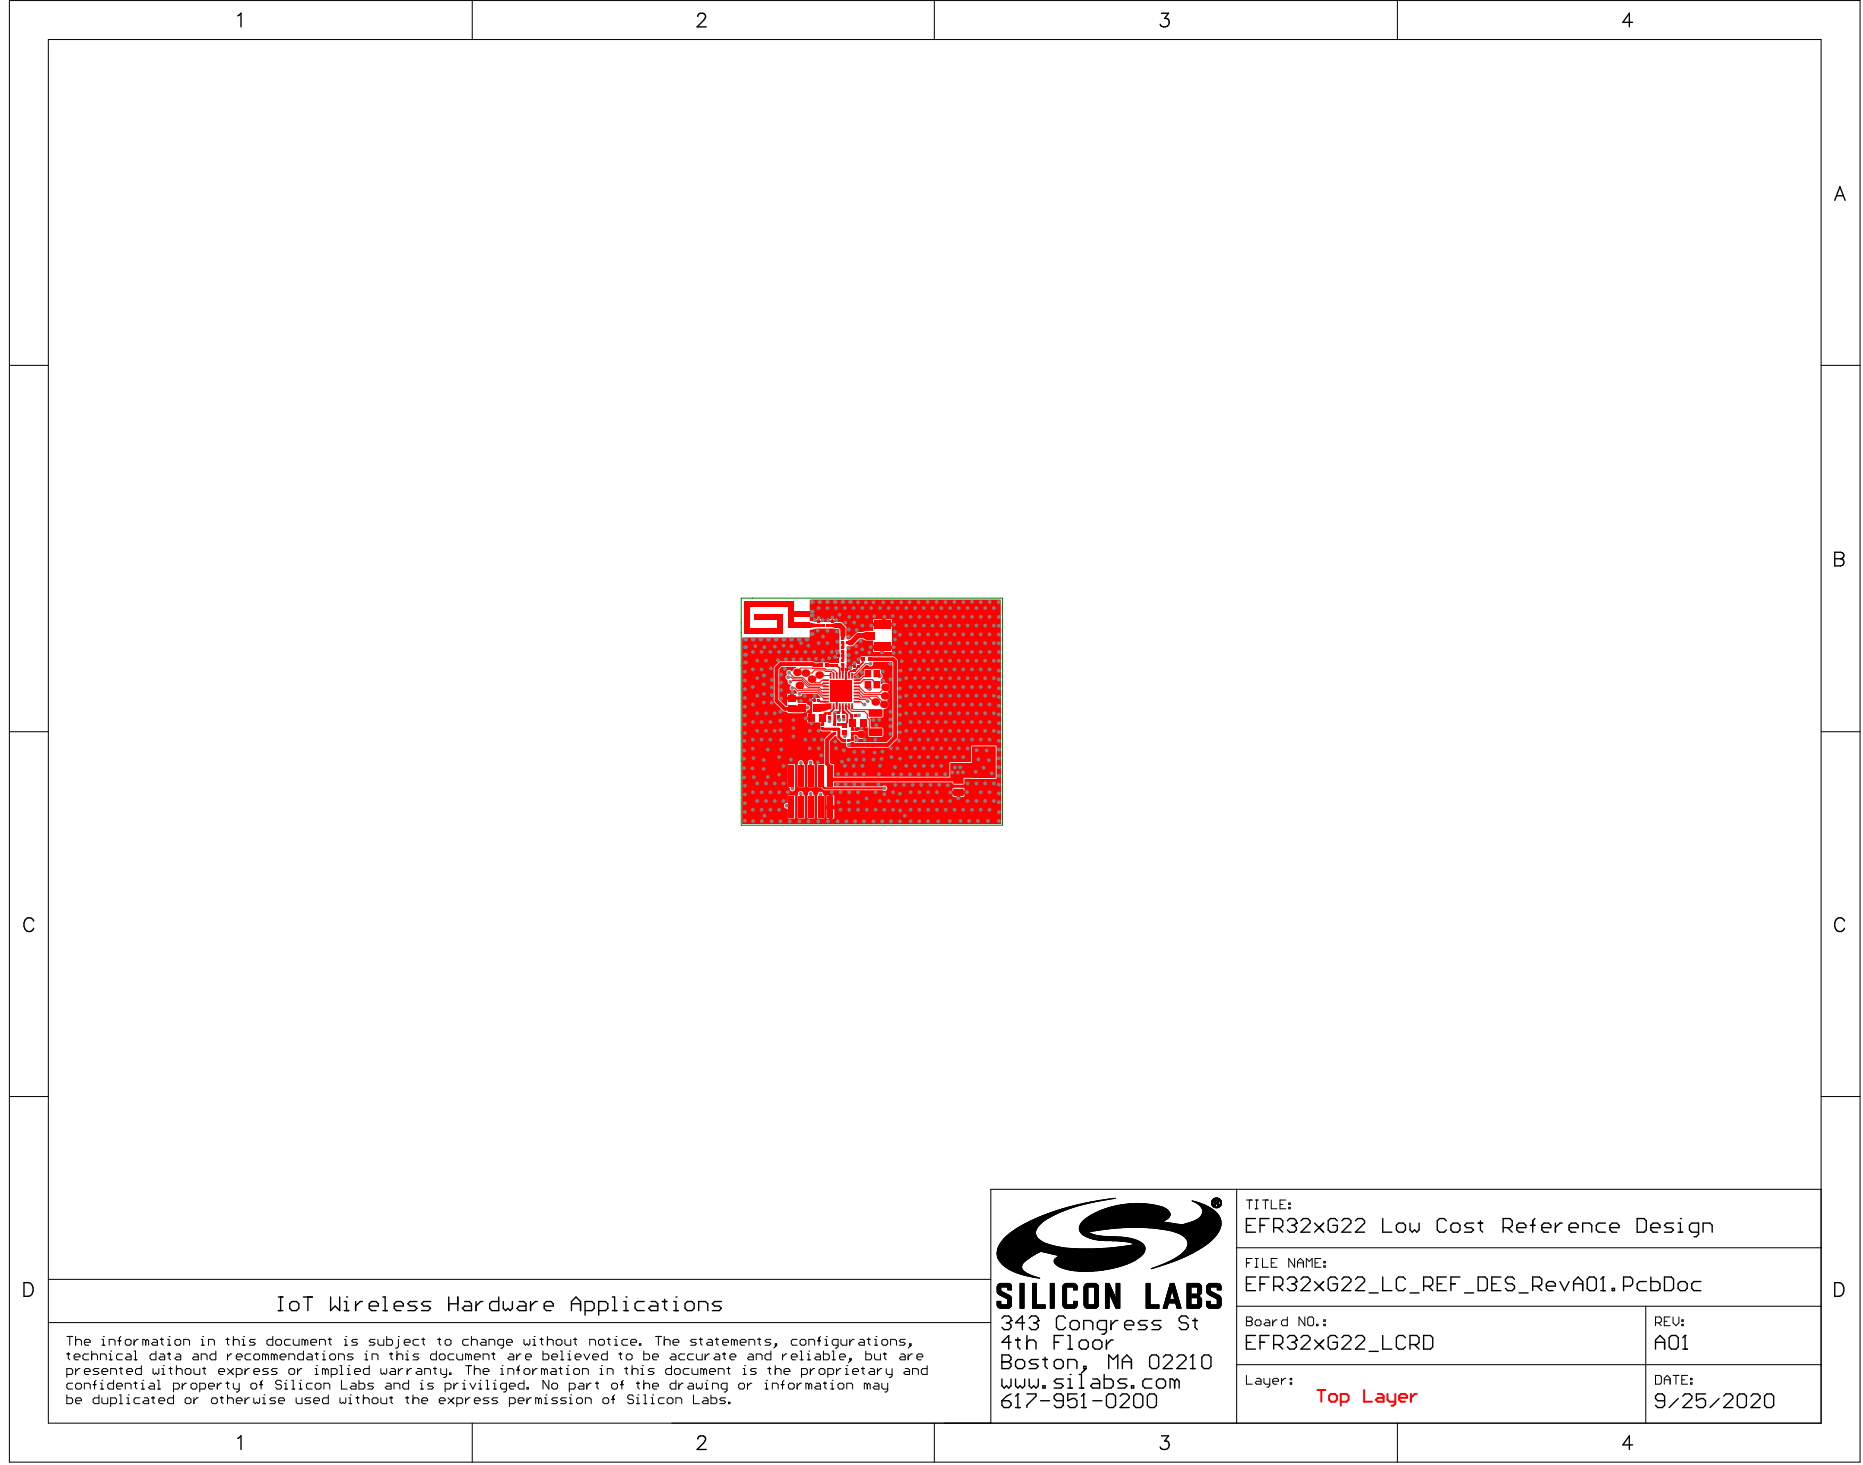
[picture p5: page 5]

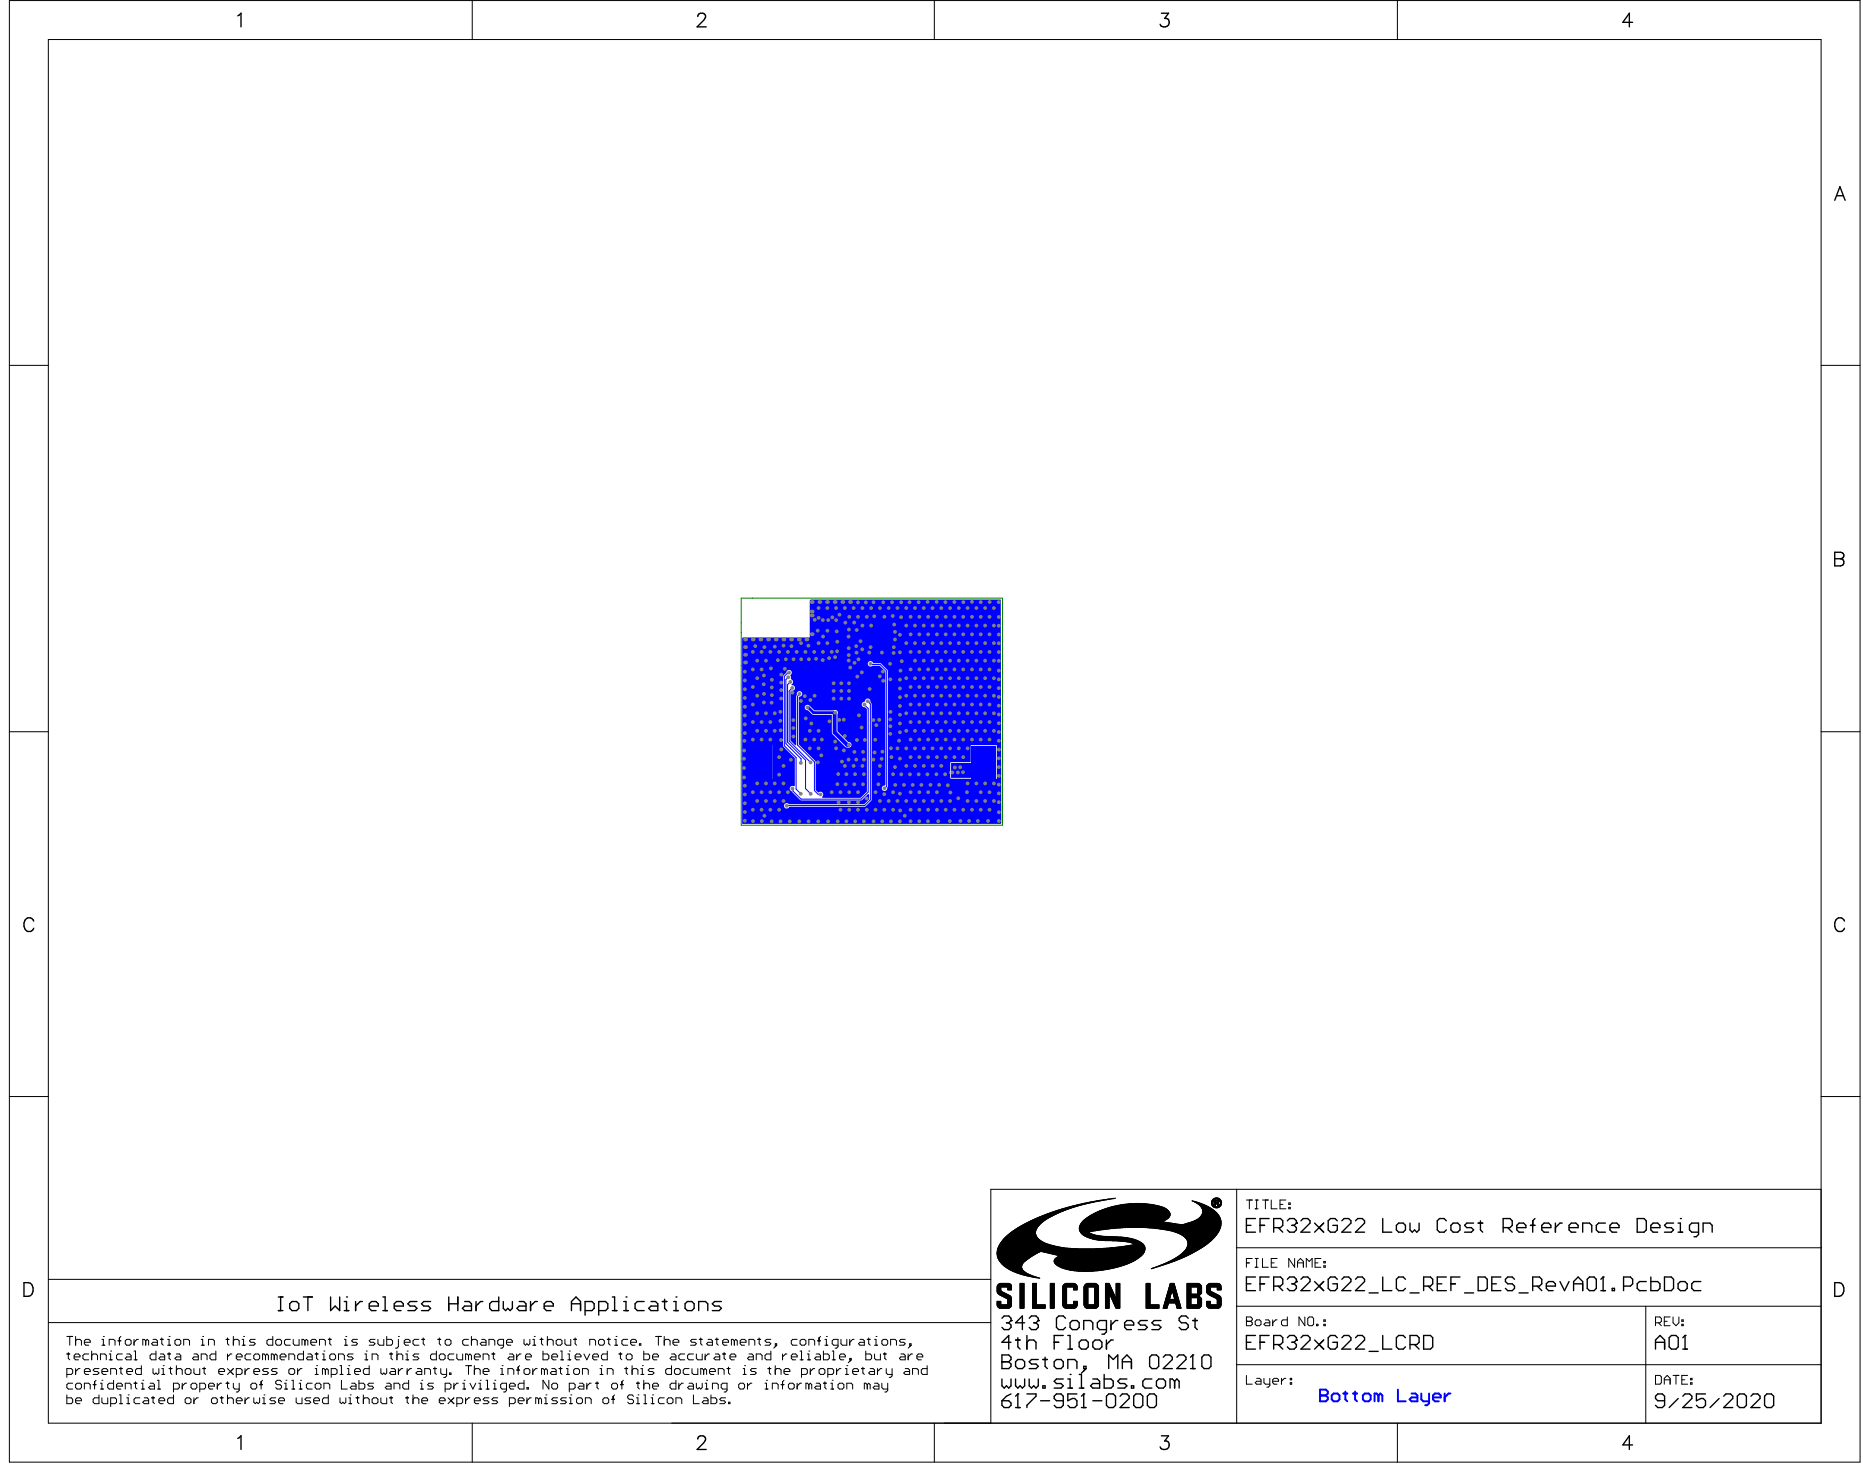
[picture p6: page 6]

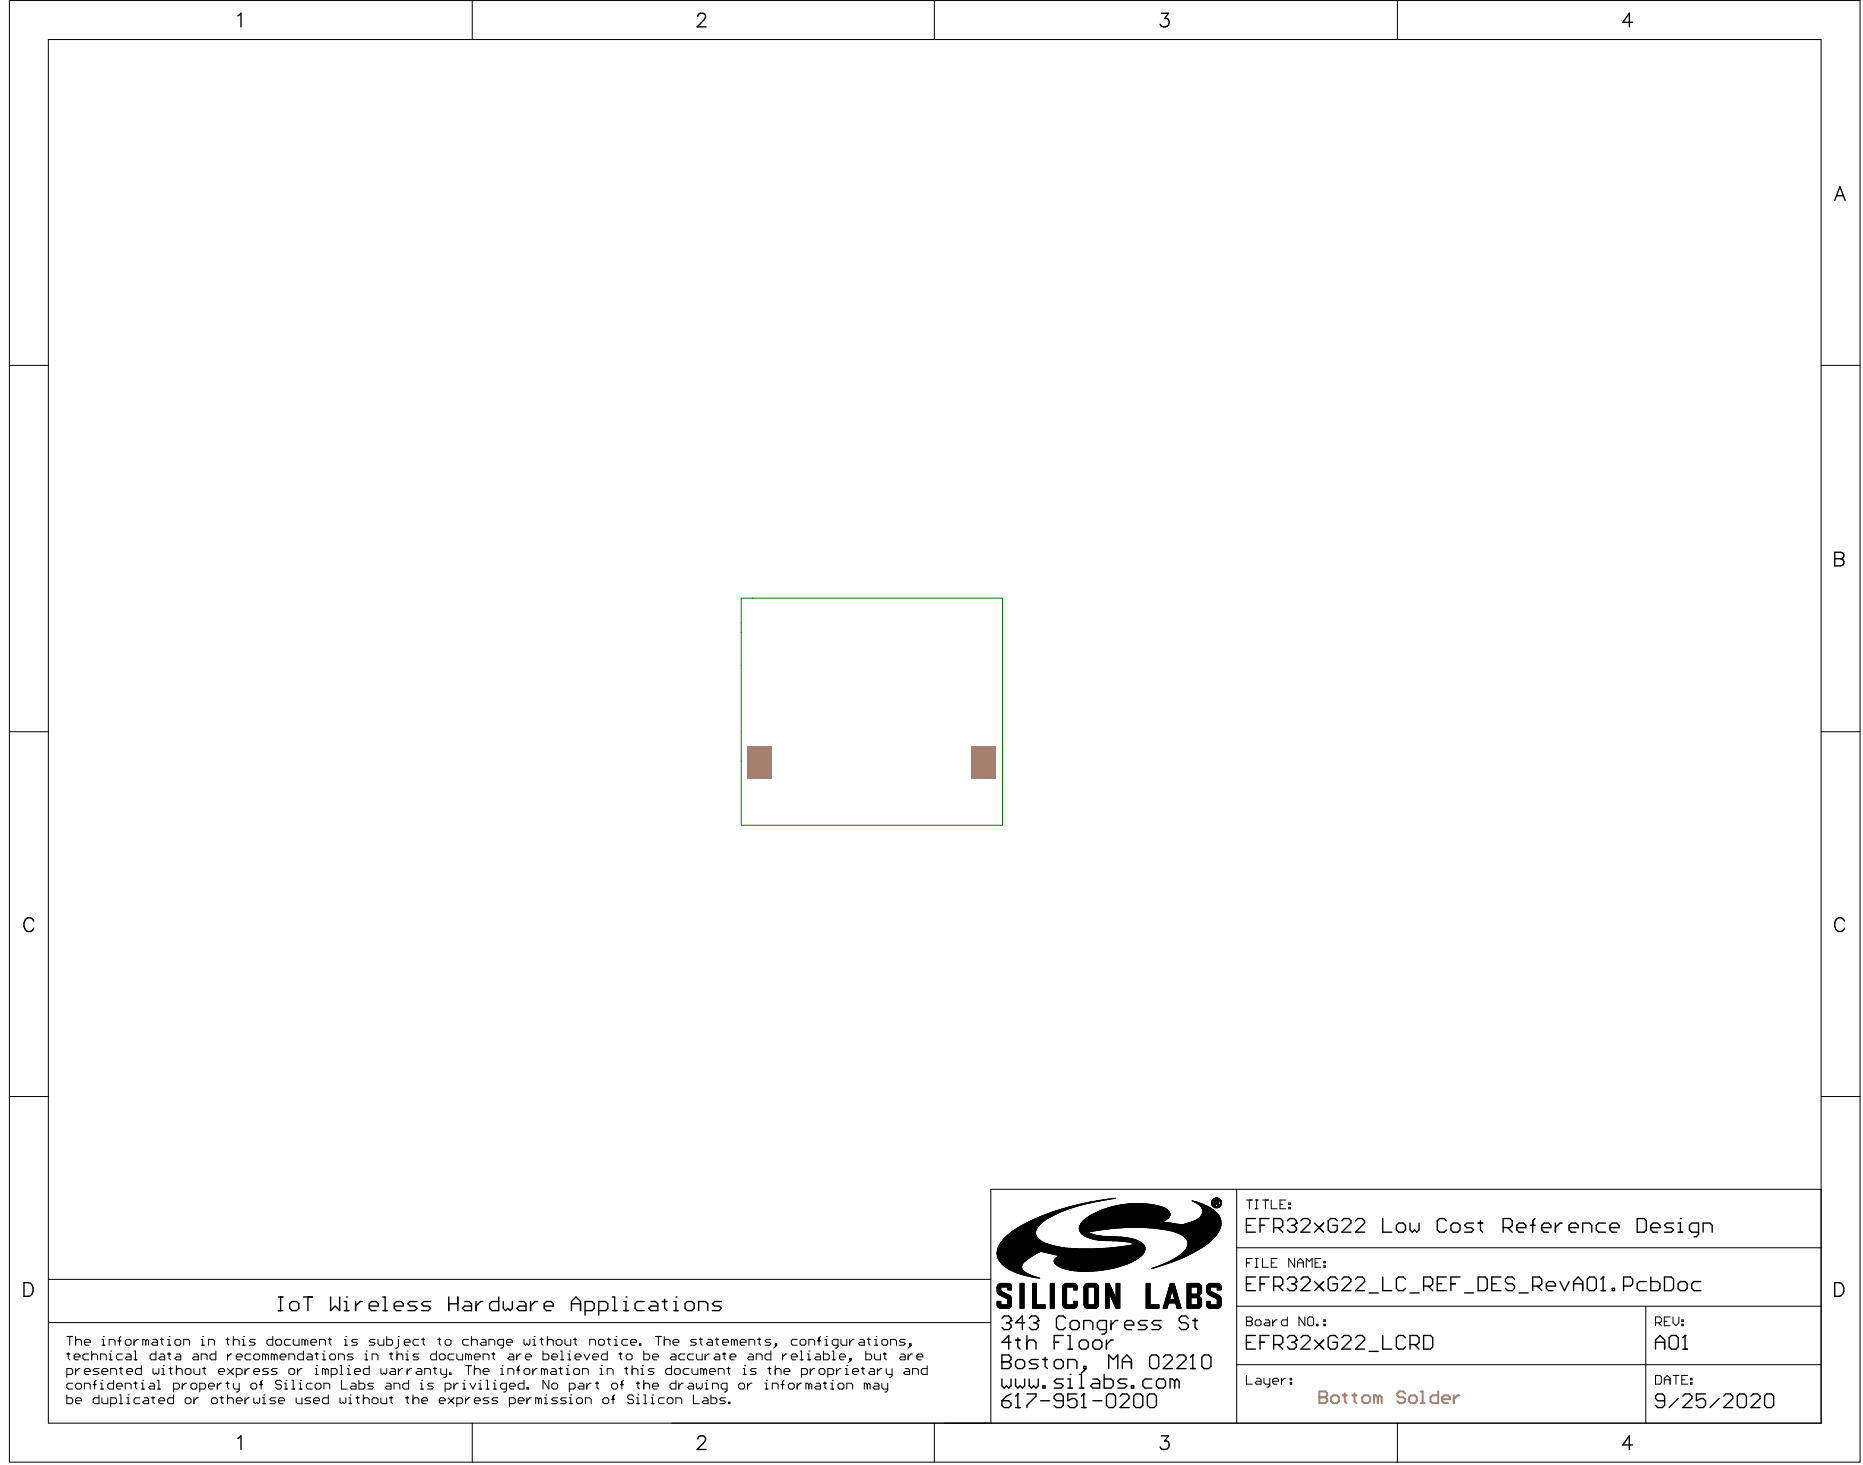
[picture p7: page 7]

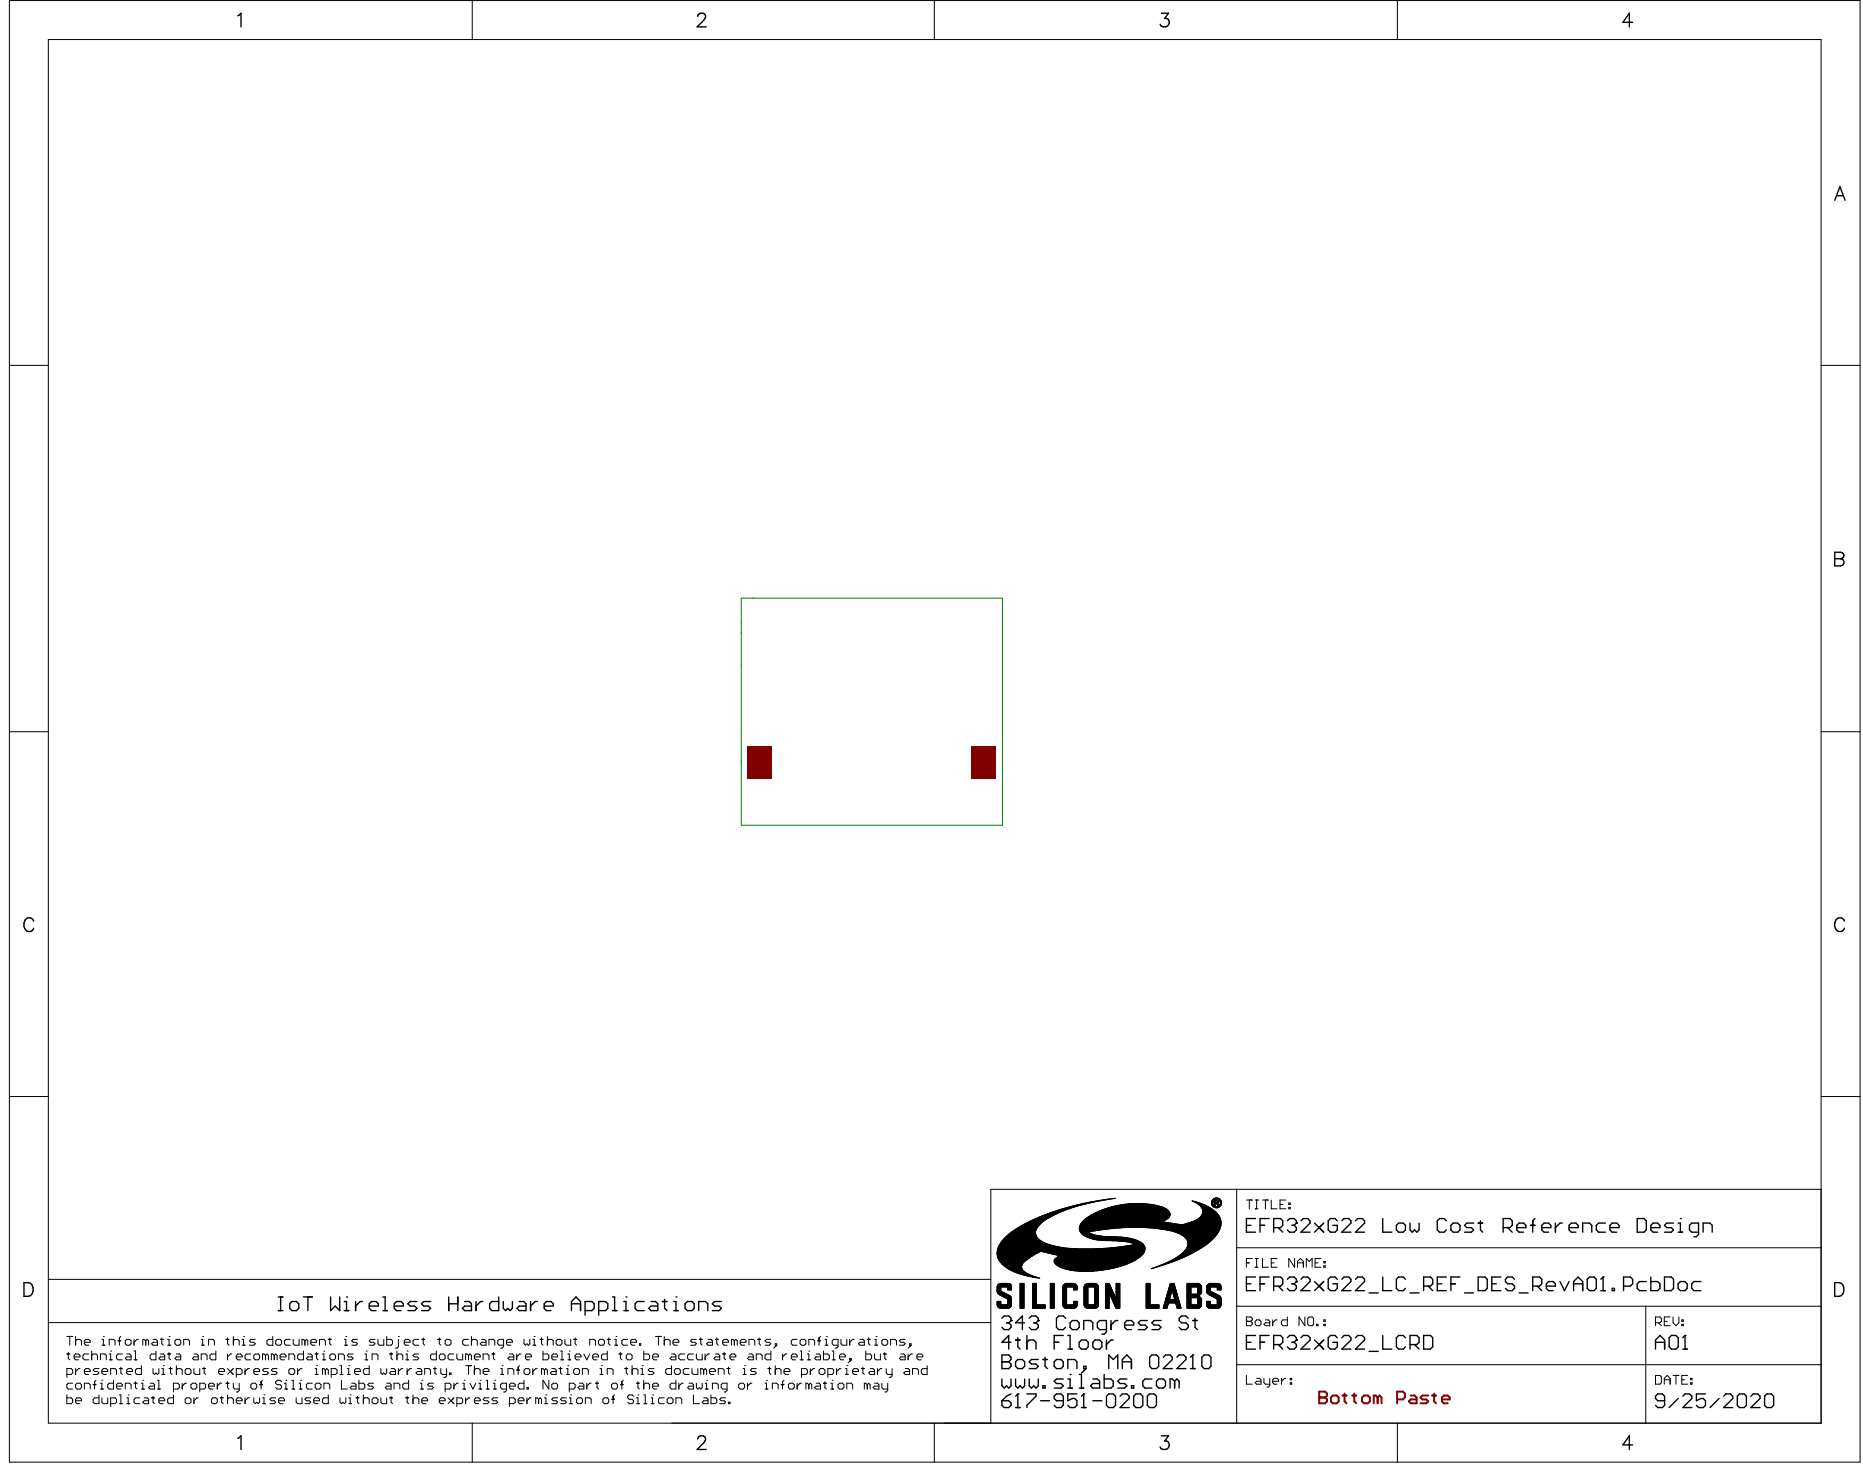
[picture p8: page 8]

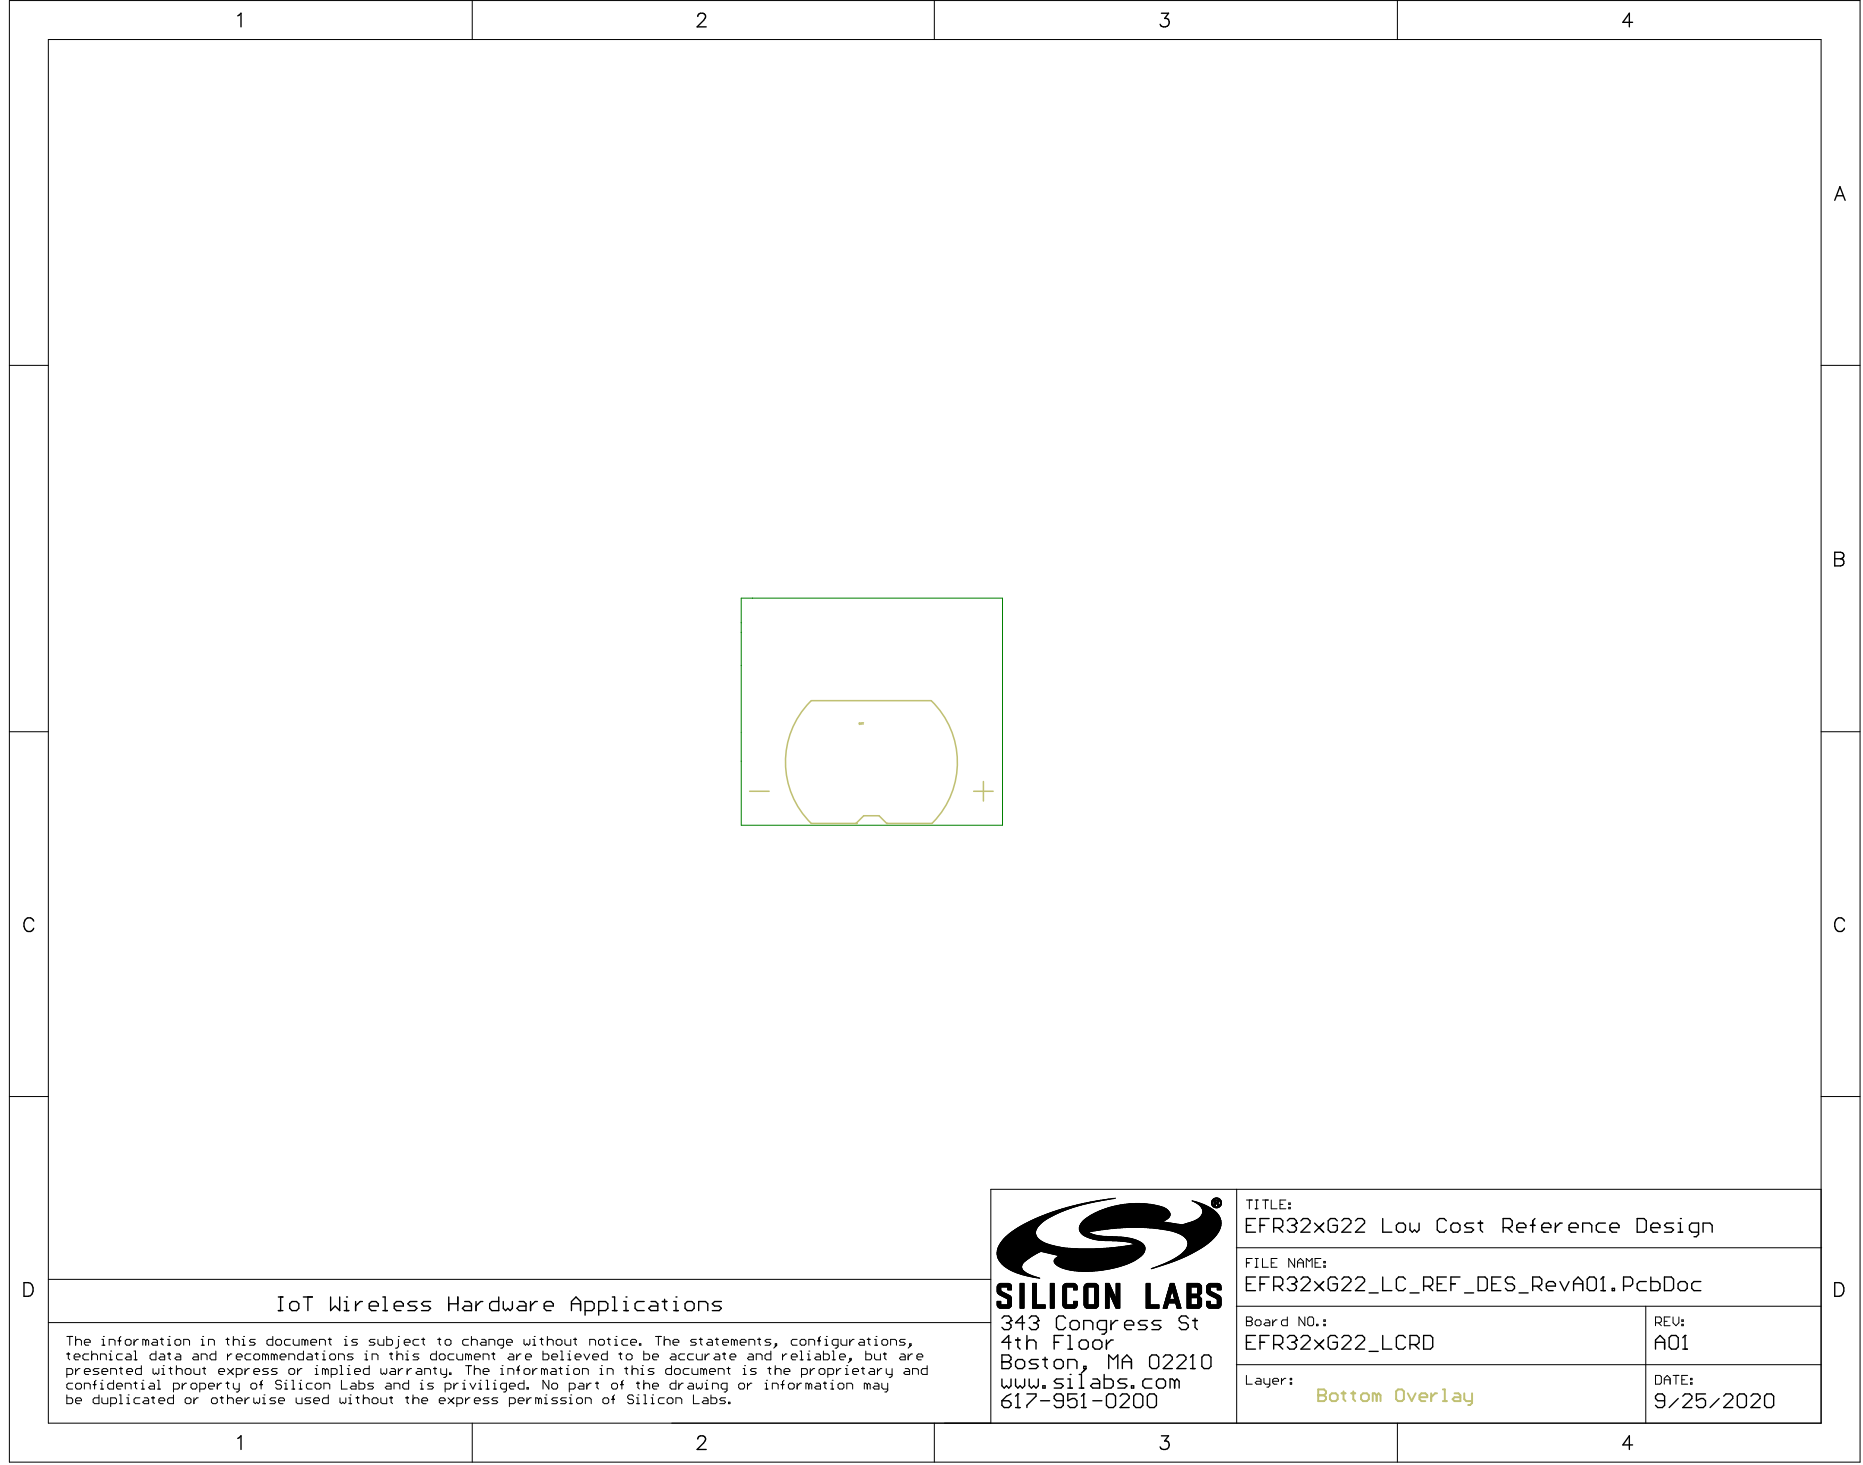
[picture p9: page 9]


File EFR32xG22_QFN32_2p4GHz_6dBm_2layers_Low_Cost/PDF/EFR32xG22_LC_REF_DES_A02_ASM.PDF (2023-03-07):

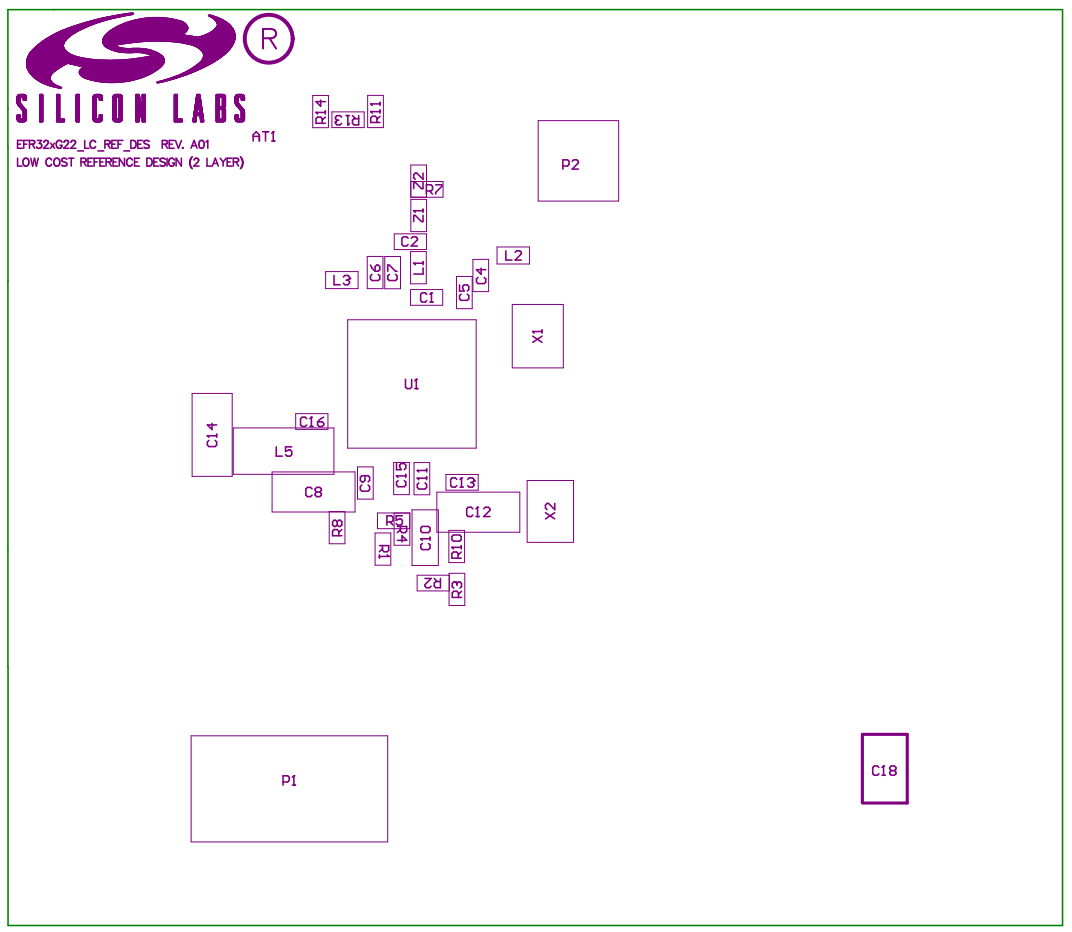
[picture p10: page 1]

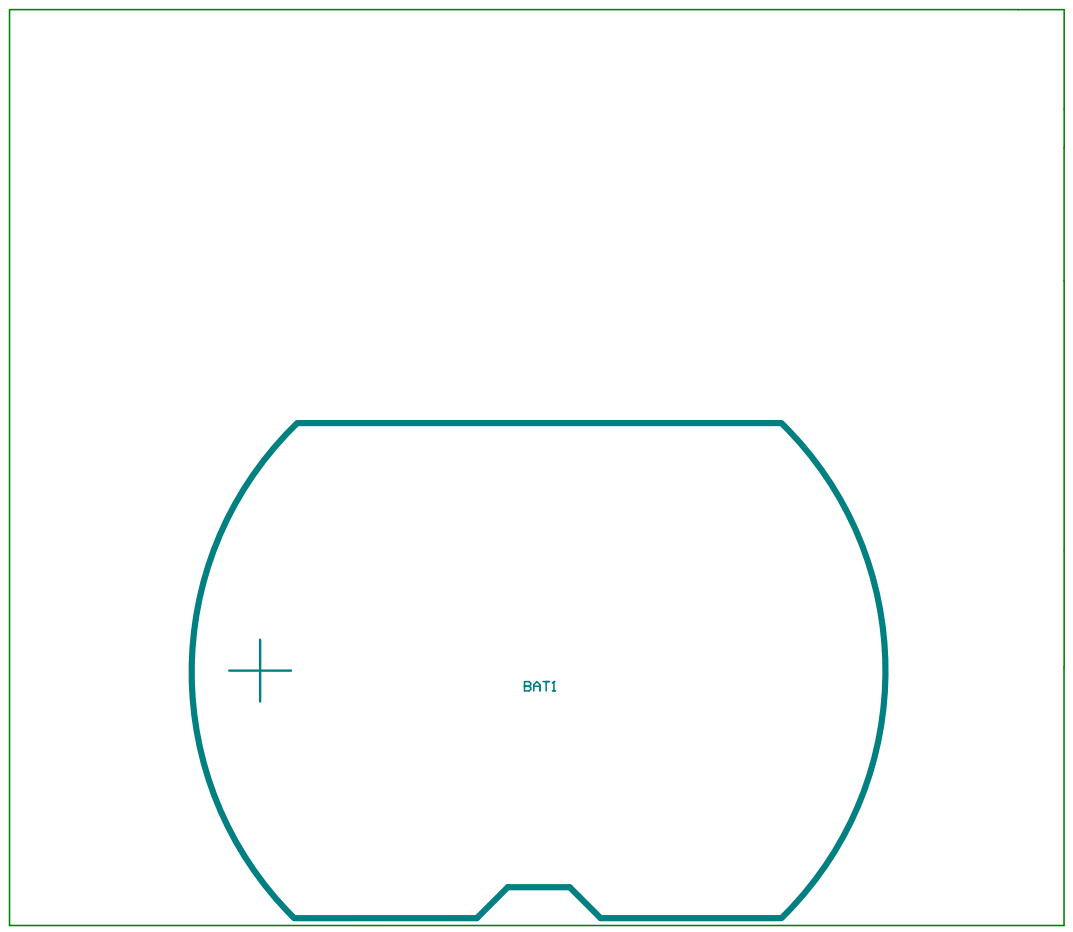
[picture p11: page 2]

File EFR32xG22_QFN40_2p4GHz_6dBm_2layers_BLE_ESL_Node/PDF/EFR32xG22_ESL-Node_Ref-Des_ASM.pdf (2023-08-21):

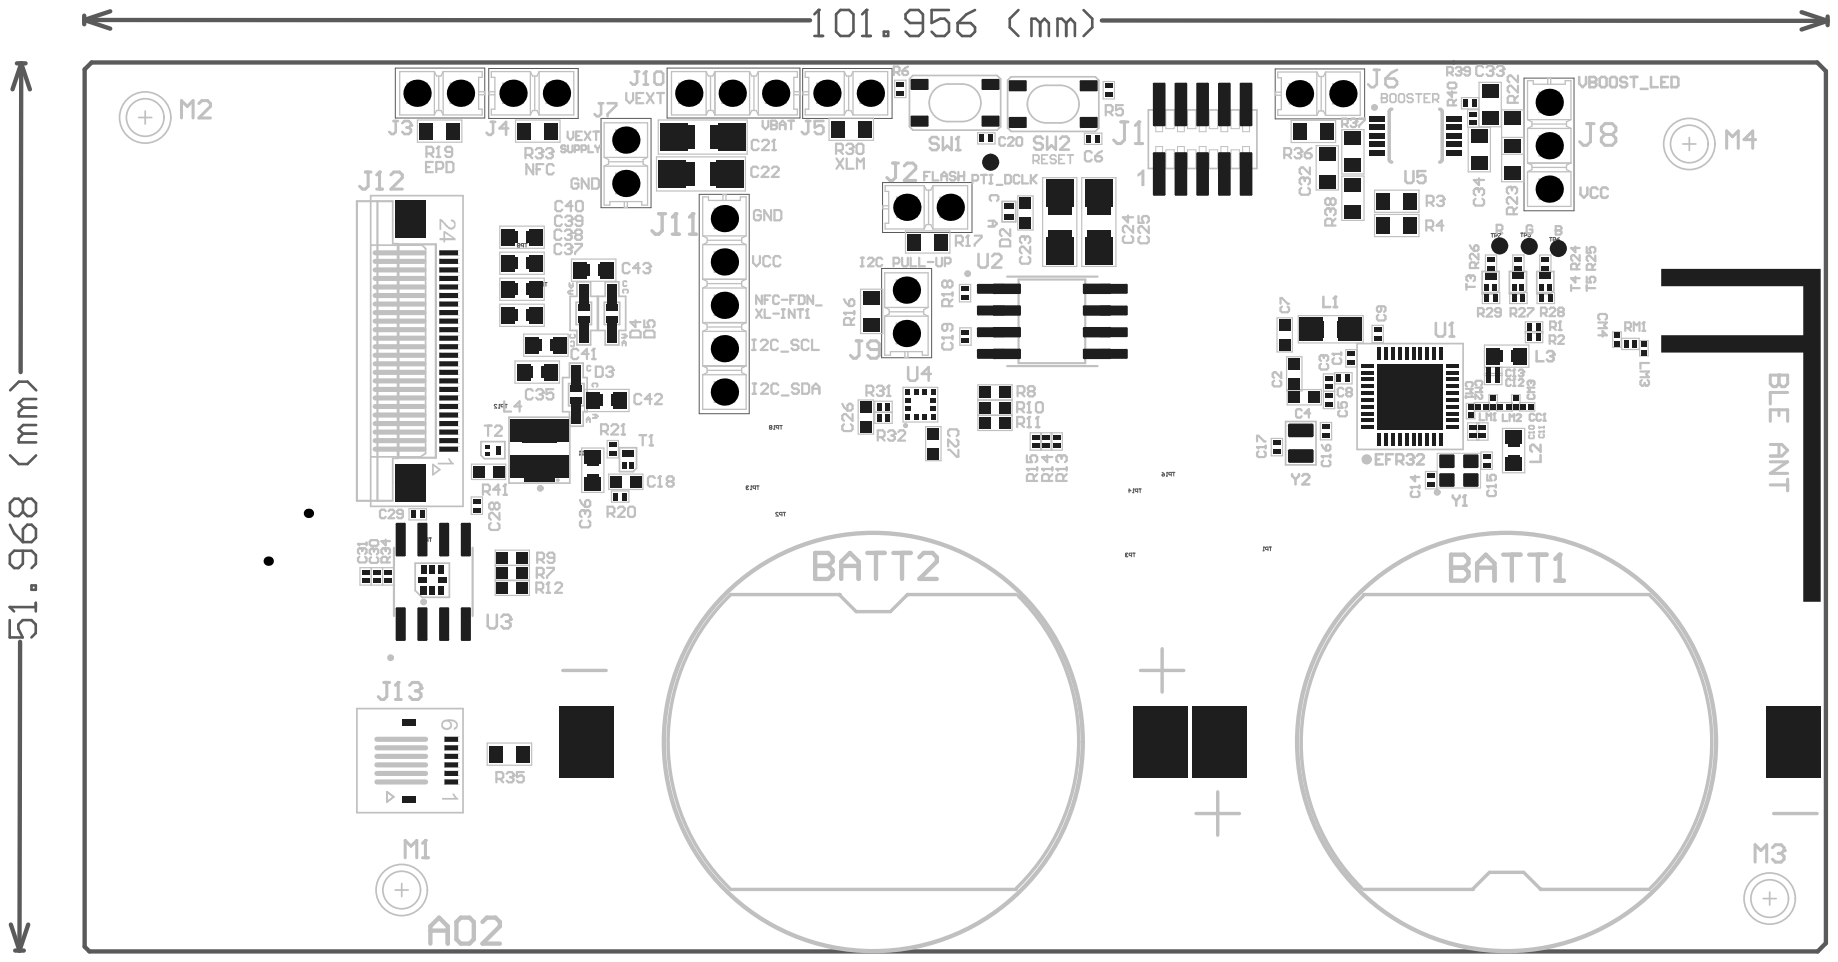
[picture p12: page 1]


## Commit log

2023-03-07 Adding EFR32xG22 Low Cost and BLE Tag Reference Designs
    [EFR32BG22_TAG_REF_DES_A01.sch, EFR32BG22_TAG_REF_DES_A01_BOM.xlsx, EFR32BG22_TAG_REF_DES_A01_PCB_spec.xls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]
2023-08-21 Adding BLE ESL Node reference design pack
    [EFR32xG22_ESL-Node_Ref-Des.GBL, EFR32xG22_ESL-Node_Ref-Des.GBO, EFR32xG22_ESL-Node_Ref-Des.GBP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]
